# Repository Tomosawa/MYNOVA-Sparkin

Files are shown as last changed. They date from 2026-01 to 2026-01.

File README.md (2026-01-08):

# MYNOVA-Sparkin

[中文文档](README_CHS.md) | [English](README.md)

## Overview

MYNOVA-Sparkin is a wireless Bluetooth fingerprint recognition device for Windows computers. It provides fast fingerprint identification (0.5 seconds), local fingerprint management, and system login integration. The project includes complete hardware design, firmware, and Windows supporting software.

Sparkin Overview
Sparkin Overview
Sparkin Overview
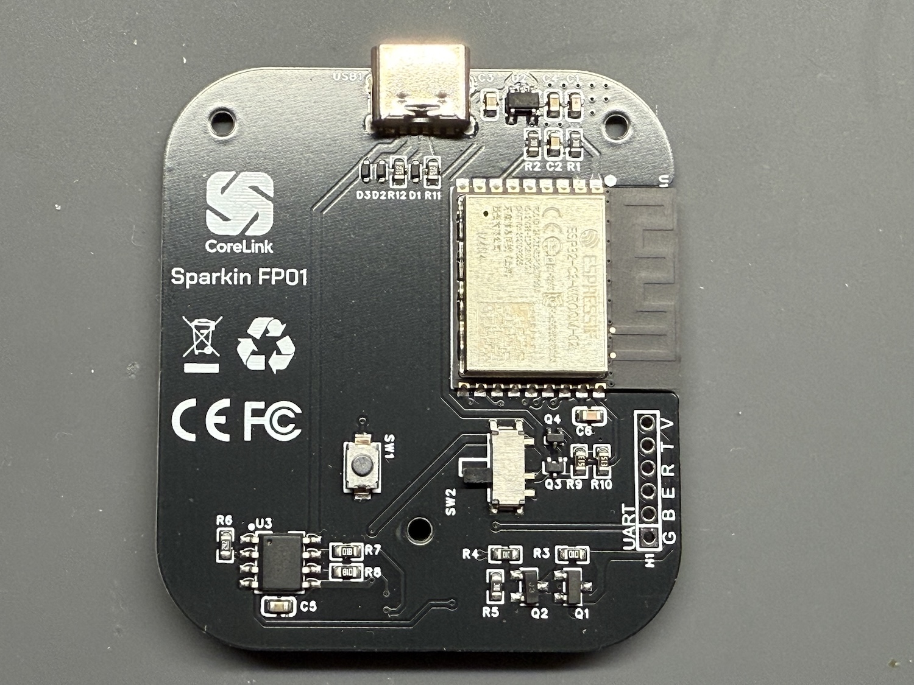
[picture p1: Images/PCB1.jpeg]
Sparkin PCB1

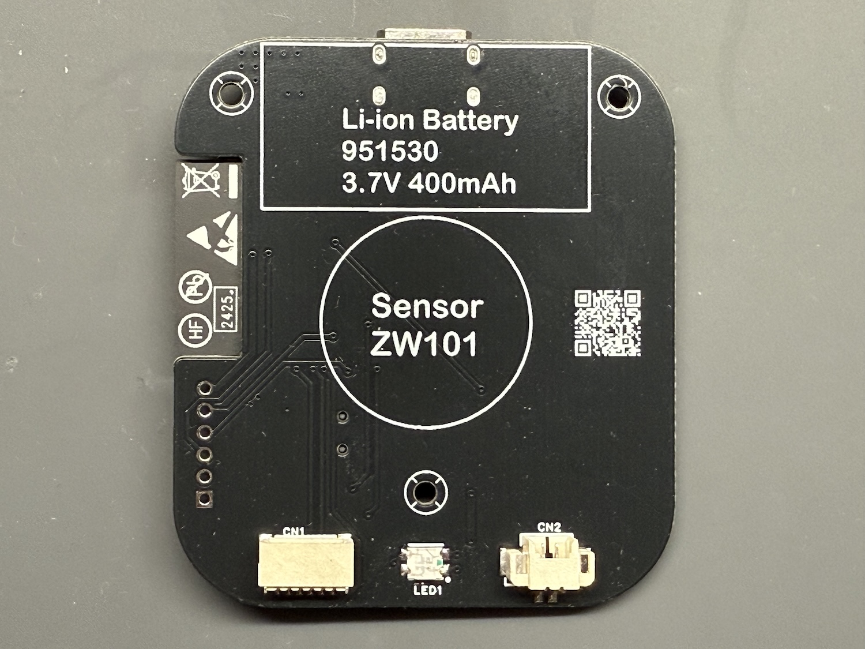
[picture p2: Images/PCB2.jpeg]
Sparkin PCB2

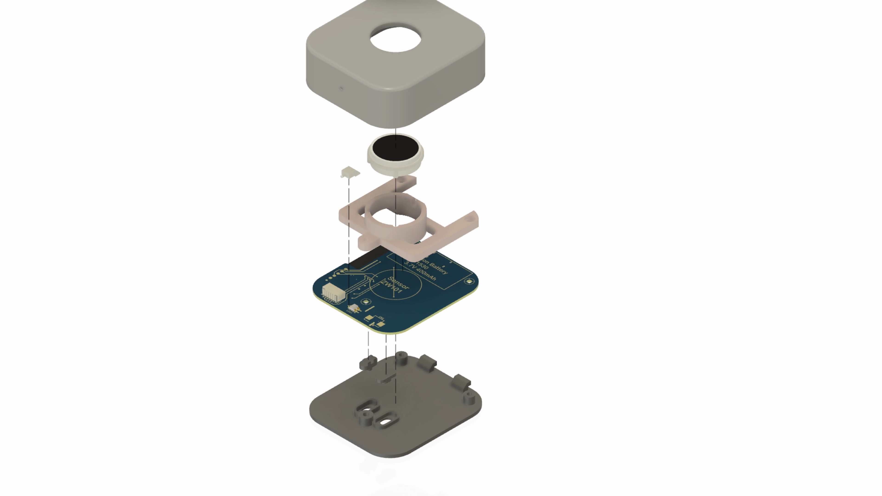
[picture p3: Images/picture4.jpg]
Sparkin Overview


## Key Features

- **Fast Recognition**: 0.5-second fingerprint identification
- **Wireless Connectivity**: Bluetooth BLE 5.0 for stable connections
- **System Integration**: Automatic Windows login when fingerprint is verified
- **Local Storage**: Fingerprints stored securely on the device
- **Portable Design**: Built-in battery with Type-C charging
- **Power Efficient**: Automatic sleep mode to conserve battery
- **OTA Updates**: Over-the-air firmware update support

## Getting Started

### Prerequisites

- Windows 10/11 computer with Bluetooth support
- Type-C charging cable (for initial device charging)

### Installation

1. Download the latest Windows installer from the [Releases](https://github.com/tomosawa/MYNOVA-Sparkin/releases) page
2. Run the installer and follow the on-screen instructions
3. After installation, the Sparkin service will start automatically
4. Launch the Sparkin configuration client from the Start menu

### Device Pairing

1. Press and hold the pairing button for 3 seconds until the LED blinks
2. Open the Sparkin configuration client
3. Click "Add Device" and select "Sparkin FP01"
4. Follow the instructions to complete pairing

### Fingerprint Enrollment

1. Ensure the device is connected
2. Go to "Fingerprint Management" in the client
3. Click "Enroll New Fingerprint"
4. Scan your fingerprint multiple times as instructed
5. Assign a name to the fingerprint

### System Login Setup

1. Go to "Login Settings" in the client
2. Enable "Automatic Login with Fingerprint"
3. Enter your Windows login password
4. Click "Save" to complete setup

## Project Structure

```
MYNOVA-Sparkin/
├── SparkinFW/          # Device firmware (Arduino/ESP32-C3)
├── SparkinWin/         # Windows application and setup
├── 3DModels/           # Enclosure 3D models
├── Labels/             # Label design files
└── PCB/                # PCB design files
```

### SparkinFW
Device firmware built on Arduino framework for ESP32-C3, featuring:
- Fingerprint sensor management
- Bluetooth BLE communication
- Power and battery management
- Sleep mode control
- OTA update support

### SparkinWin
Windows supporting applications:
- Background service for Bluetooth communication
- Configuration client for device management
- Fingerprint enrollment interface
- System login integration

## Development

### Firmware Development

- **IDE**: Arduino IDE 2.3.6+
- **ESP32 Core**: 3.1.1+
- **Language**: C++

### Windows Application Development

- **IDE**: Visual Studio 2022
- **Framework**: Windows SDK for Windows 10/11
- **Language**: C#/C++

## Documentation

For detailed technical documentation:
- [Firmware Architecture](docs/firmware-architecture.md)
- [Windows Application Guide](docs/windows-application.md)

## Contributing

Contributions are welcome! Please follow these steps:

1. Fork the repository
2. Create a feature branch
3. Make your changes
4. Submit a pull request

## Copyright Statement

This project is prohibited for any commercial use and is intended for learning and DIY purposes only.

## License [LICENSE](LICENSE)

This project is licensed under the [GPLv3](LICENSE). [GPLv3 (GNU General Public License version 3)](LICENSE) is a free, open-source software license that guarantees users the freedoms to run, study, share, and modify the software.
The complete text of the [GPLv3](LICENSE) license is included in the [LICENSE](LICENSE) file of this project. Before using, modifying, or distributing the code of this project, make sure you have read and understood the entire [GPLv3](LICENSE) license.

## Acknowledgments

- [Espressif Systems](https://www.espressif.com/) for ESP32-C3
- [Arduino Framework](https://www.arduino.cc/) community
- [Bluetooth SIG](https://www.bluetooth.com/) for BLE standards
- [Microsoft Learn](https://learn.microsoft.com/en-us/windows/win32/secauthn/credential-providers-in-windows) for Windows credential provider documentation
---

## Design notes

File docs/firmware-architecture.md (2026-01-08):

# SparkinFW Firmware Architecture

## Overview

SparkinFW is the firmware for the MYNOVA-Sparkin wireless Bluetooth fingerprint recognition device. It's built on the Arduino framework for the ESP32-C3 microcontroller and implements a modular architecture to manage all device functionalities.

## System Architecture

The firmware follows a modular design pattern with clear separation of concerns:

```
┌─────────────────────────────────────────────────────────────────┐
│                         Main Program                            │
│                        (SparkinFW.ino)                          │
└─────────────┬───────────────────┬───────────────────┬───────────┘
              │                   │                   │
┌─────────────▼─────────┐ ┌───────▼─────────────┐ ┌───▼───────────────┐
│  Fingerprint Module   │ │  Bluetooth Module   │ │ Power Management  │
│  (Fingerprint.cpp/h)  │ │  (BleKeyboard.cpp/h,│ │ (BatteryManager.  │
│                       │ │  BluetoothManager.  │ │  cpp/h, Sleep.cpp │
│                       │ │  cpp/h, BluetoothHa │ │  /h)              │
│                       │ │  ndle.cpp/h)        │ │                   │
└─────────────┬─────────┘ └───────┬─────────────┘ └─┬─────────────────┘
              │                   │                 │
┌─────────────▼─────────┐ ┌───────▼─────────────┐ ┌─▼─────────────────┐
│ Button Management     │ │ OTA Update          │ │ Config Management │
│ (ButtonHandle.cpp/h,  │ │ (BluetoothOTA.cpp/h)│ │ (ConfigManager.   │
│ ButtonTimer.cpp/h)    │ │                     │ │  cpp/h)           │
└─────────────┬─────────┘ └─────────────────────┘ └───────────────────┘
              │
┌─────────────▼─────────┐
│ Common Utilities      │
│ (Common.cpp/h, IOPin. │
│  h, Version.h)        │
└───────────────────────┘
```

## Core Modules

### 1. Main Program (SparkinFW.ino)

The main entry point that coordinates all modules:

- **setup()**: Initializes all hardware and software modules
- **loop()**: Main program loop handling continuous operations
- **Event handling**: Processes events from different modules
- **State management**: Maintains the overall device state

### 2. Fingerprint Module

**File**: `Fingerprint.cpp/h`

Responsible for all fingerprint-related operations:

- Initialization and configuration of the optical fingerprint sensor
- Fingerprint enrollment (storing new fingerprints)
- Fingerprint identification (matching against stored fingerprints)
- Fingerprint database management
- Fingerprint template encryption

### 3. Bluetooth Module

**Files**: `BluetoothManager.cpp/h`, `BleKeyboard.cpp/h`, `BluetoothHandle.cpp/h`

Handles all wireless communication:

- **BLE Server**: Manages Bluetooth connections and services
- **Characteristic Management**: Handles data exchange between device and Windows
- **Message Protocol**: Implements custom message format for communication
- **BleKeyboard**: Emulates keyboard input for Windows login
- **Advertising**: Manages device discovery and pairing
- **Connection Handling**: Manages Bluetooth connection states and events

Key Bluetooth UUIDs:
- Service UUID: `0000180f-0000-1000-8000-00805f9b34fb`
- Characteristic UUIDs: Custom for fingerprint data and commands

### 4. Power Management

**Files**: `BatteryManager.cpp/h`, `Sleep.cpp/h`

Manages device power consumption:

- **Battery Monitoring**: Measures battery voltage and level
- **Charging Management**: Handles Type-C charging state
- **Sleep Mode**: Automatic sleep after period of inactivity
- **Wake-up**: Fingerprint sensor or button wake-up triggers
- **Power Optimization**: Controls peripheral power states

### 5. Button Management

**Files**: `ButtonHandle.cpp/h`, `ButtonTimer.cpp/h`

Handles physical button operations:

- **Button Press Detection**: Monitors pairing button state
- **Long Press Handling**: 3-second press for pairing mode
- **Button Debouncing**: Eliminates false triggers
- **Timer Functions**: Implements timed button operations

### 6. OTA Update

**File**: `BluetoothOTA.cpp/h`

Enables over-the-air firmware updates:

- **Secure Updates**: Validates firmware signatures
- **Update Process**: Manages firmware download and installation
- **Rollback**: Automatic recovery if update fails
- **Version Check**: Ensures compatible firmware versions

### 7. Configuration Management

**File**: `ConfigManager.cpp/h`

Stores and retrieves device configuration:

- **Persistent Storage**: Uses ESP32 non-volatile storage
- **Configuration Parameters**:
  - Bluetooth name and settings
  - Sleep timeout
  - Fingerprint matching threshold
  - Device ID and settings
- **Factory Reset**: Restores default configuration

### 8. Common Utilities

**Files**: `Common.cpp/h`, `IOPin.h`, `Version.h`

Shared functionality across modules:

- **Pin Definitions**: Centralized IO pin mapping
- **Debug Functions**: Logging and debugging utilities
- **Version Information**: Firmware version tracking
- **Data Structures**: Common data types and structures
- **Helper Functions**: String manipulation, data conversion, etc.

## Main Program Flow

### Initialization Flow

```
1. System boot
2. Initialize common utilities and pin mappings
3. Initialize configuration manager
4. Initialize battery management
5. Initialize fingerprint module
6. Initialize Bluetooth services
7. Initialize button handling
8. Initialize sleep management
9. Start main loop
```

### Fingerprint Recognition Flow

```
1. Fingerprint sensor detects touch
2. Capture fingerprint image
3. Extract fingerprint features
4. Match against stored templates
5. If match found:
   a. Send success message via Bluetooth
   b. Trigger Windows login if configured
6. If no match:
   a. Send failure message via Bluetooth
   b. Optionally alert user (LED feedback)
```

## Communication Protocol

The device uses a custom binary protocol over Bluetooth BLE for communication with the Windows application:

### Message Format

```
┌────────────┬────────────┬───────────┐
│ Message ID │ Data Length│   Data    │
└────────────┴────────────┴───────────┘
  (1 byte)    (1 byte)    (N bytes)
```

### Key Message Types

| Message ID | Description | Direction |
|---|---|---|
| 0x01 | Fingerprint Search Result | Device → PC |
| 0x02 | Enroll Fingerprint Request | PC → Device |
| 0x03 | Enroll Fingerprint Result | Device → PC |
| 0x04 | Delete Fingerprint Request | PC → Device |
| 0x05 | Device Status Request | PC → Device |
| 0x06 | Device Status Response | Device → PC |
| 0x07 | Configuration Update | PC → Device |
| 0x08 | Sleep Mode Request | PC → Device |
| 0x09 | Wake-up Request | PC → Device |

## Power States

| State | Description | Power Consumption |
|---|---|---|
| Active | Full functionality | High |
| Standby | Bluetooth active, fingerprint sensor ready | Medium |
| Sleep | Bluetooth off, fingerprint sensor on standby | Low |
| Deep Sleep | Minimal functionality, wake-up on touch | Very Low |

## Development Guide

### Prerequisites

- Arduino IDE 2.3.6+
- ESP32 Core 3.1.1+
- ESP32-C3 development board
- Required libraries:
  - ESP32 BLE Arduino
  - ArduinoJson
  - Adafruit Fingerprint Sensor Library

### Building and Flashing

1. Open `SparkinFW.ino` in Arduino IDE
2. Select "ESP32C3 Dev Module" as the board
3. Select the appropriate port
4. Click "Upload" to flash the firmware

### Debugging

- Use Serial Monitor at 115200 baud for debug messages
- Check Bluetooth logs in Windows application
- Use LED indicators for device state (pairing, charging, etc.)

## Version History

| Version | Date | Changes |
|---|---|---|
| 1.0.0 | 2023-12-15 | Initial release |
| 1.0.1 | 2023-12-20 | Fixed battery reporting |
| 1.1 | 2024-01-05 | Added OTA update support |

---

[Back to README](../README.md)

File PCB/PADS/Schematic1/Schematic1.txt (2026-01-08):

*PADS-LOGIC-V9.0-CP936* from EasyEDA Pro
*SCH*
BORDER NAME Sheet_WMY_A4
*SHT* 2 P1 -1 $$$NONE
*TEXT*
2415 6165 0 0 348 10 0 "Regular Arial"
单片机
1965 4265 0 0 348 10 0 "Regular Arial"
3.3V供电电路
865 115 0 0 348 10 0 "Regular Arial"
Type-C插口（ESD）
2415 2075 0 0 348 10 0 "Regular Arial"
充电电路
3715 165 0 0 348 10 0 "Regular Arial"
电池插口
9765 865 0 0 348 10 0 "Regular Arial"
电量检测
6365 4265 0 0 348 10 0 "Regular Arial"
指纹模块低功耗控制
9615 4215 0 0 348 10 0 "Regular Arial"
指纹模块连接器
7065 815 0 0 348 10 0 "Regular Arial"
按钮/开关
5265 165 0 0 348 10 0 "Regular Arial"
螺丝孔
*LINES*
Sheet_WMY_A4 LINES 0 0 24 31
OPEN 2 10 255
7995 115
7995 715
OPEN 2 10 255
6815 715
6815 115
OPEN 2 10 255
11615 515
6215 515
OPEN 2 10 255
11615 715
6215 715
OPEN 2 10 255
9195 715
9195 115
OPEN 2 10 255
6215 715
6215 115
CLOSED 5 10 255
15 8265
11715 8265
11715 15
15 15
15 8265
CLOSED 5 10 255
115 8165
11615 8165
11615 115
115 115
115 8165
OPEN 2 10 255
1965 15
1965 115
OPEN 2 10 255
1965 8265
1965 8165
OPEN 2 10 255
3915 15
3915 115
OPEN 2 10 255
3915 8265
3915 8165
OPEN 2 10 255
5865 15
5865 115
OPEN 2 10 255
5865 8265
5865 8165
OPEN 2 10 255
7815 15
7815 115
OPEN 2 10 255
7815 8265
7815 8165
OPEN 2 10 255
9765 15
9765 115
OPEN 2 10 255
9765 8265
9765 8165
OPEN 2 10 255
15 6202
115 6202
OPEN 2 10 255
11715 6202
11615 6202
OPEN 2 10 255
15 4140
115 4140
OPEN 2 10 255
11715 4140
11615 4140
OPEN 2 10 255
15 2077
115 2077
OPEN 2 10 255
11715 2077
11615 2077
7415 615 0 12 208 10 0 "Regular 宋体"
创建日期
9265 625 0 8 208 10 0 "Regular 宋体"
页
10335 625 0 8 208 10 0 "Regular 宋体"
共
8615 615 0 12 208 10 0 "Regular 宋体"
更新日期
6515 615 0 12 208 10 0 "Regular 宋体"
作者
990 65 0 12 139 10 0 "Regular 宋体"
1
990 8215 0 12 139 10 0 "Regular 宋体"
1
2940 65 0 12 139 10 0 "Regular 宋体"
2
2940 8215 0 12 139 10 0 "Regular 宋体"
2
4890 65 0 12 139 10 0 "Regular 宋体"
3
4890 8215 0 12 139 10 0 "Regular 宋体"
3
6840 65 0 12 139 10 0 "Regular 宋体"
4
6840 8215 0 12 139 10 0 "Regular 宋体"
4
8790 65 0 12 139 10 0 "Regular 宋体"
5
8790 8215 0 12 139 10 0 "Regular 宋体"
5
10740 65 0 12 139 10 0 "Regular 宋体"
6
10740 8215 0 12 139 10 0 "Regular 宋体"
6
65 7233 0 12 139 10 0 "Regular 宋体"
A
11665 7233 0 12 139 10 0 "Regular 宋体"
A
65 5171 0 12 139 10 0 "Regular 宋体"
B
11665 5171 0 12 139 10 0 "Regular 宋体"
B
65 3108 0 12 139 10 0 "Regular 宋体"
C
11665 3108 0 12 139 10 0 "Regular 宋体"
C
65 1046 0 12 139 10 0 "Regular 宋体"
D
11665 1046 0 12 139 10 0 "Regular 宋体"
D
10415 315 0 12 278 10 0 "Regular Arial"
SparkinFP01
11035 625 0 12 208 10 0 "Regular Arial"
1
8615 315 0 12 208 10 0 "Regular Arial"
2025-07-31
7415 315 0 12 208 10 0 "Regular Arial"
2025-07-05
9865 625 0 12 208 10 0 "Regular Arial"
1
6315 315 0 8 208 10 0 "Regular Arial"
Tomosawa
$$Line1 LINES 0 0 1 0
OPEN 2 10 255
6215 715
6215 4115
$$Line2 LINES 0 0 1 0
OPEN 2 10 255
5615 6065
115 6065
$$Line3 LINES 0 0 1 0
OPEN 2 10 255
11615 4115
115 4115
$$Line4 LINES 0 0 1 0
OPEN 2 10 255
8815 4115
8815 715
$$Line5 LINES 0 0 1 0
OPEN 2 10 255
6215 1965
115 1965
$$Line6 LINES 0 0 1 0
OPEN 2 10 255
3365 1965
3365 115
$$Line7 LINES 0 0 1 0
OPEN 2 10 255
9015 8165
9015 4115
$$Line8 LINES 0 0 1 0
OPEN 2 10 255
4865 1965
4865 115
$$Line9 LINES 0 0 1 0
OPEN 2 10 255
5615 8165
5615 4115
*CAEDECAL*
PIN 0 0 100 10 100 10 2 1 0 0 0 1
TIMESTAMP 2026.01.08.09.08.44
"Default Font"
"Default Font"
0 0 0 0 94 6 0 "Regular default"
PART-TYPE
0 0 0 0 94 6 0 "Regular default"
REF-DES
OPEN 2 10 255
0 0
100 0
PIN_1 0 0 100 10 100 10 2 1 0 0 0 1
TIMESTAMP 2026.01.08.09.08.44
"Default Font"
"Default Font"
0 0 0 0 94 6 0 "Regular default"
PART-TYPE
0 0 0 0 94 6 0 "Regular default"
REF-DES
OPEN 2 10 255
0 0
150 0
PIN_2 0 0 100 10 100 10 2 1 0 0 0 1
TIMESTAMP 2026.01.08.09.08.44
"Default Font"
"Default Font"
0 0 0 0 94 6 0 "Regular default"
PART-TYPE
0 0 0 0 94 6 0 "Regular default"
REF-DES
OPEN 2 10 255
0 0
200 0
PIN_3 0 0 100 10 100 10 2 1 0 0 0 1
TIMESTAMP 2026.01.08.09.08.44
"Default Font"
"Default Font"
0 0 0 0 94 6 0 "Regular default"
PART-TYPE
0 0 0 0 94 6 0 "Regular default"
REF-DES
OPEN 2 10 255
0 0
20 0
PIN_4 0 0 100 10 100 10 2 1 0 0 0 1
TIMESTAMP 2026.01.08.09.08.44
"Default Font"
"Default Font"
0 0 0 0 94 6 0 "Regular default"
PART-TYPE
0 0 0 0 94 6 0 "Regular default"
REF-DES
OPEN 2 10 255
0 0
50 0
PZ200V-11-06P 0 0 100 10 100 10 2 2 0 6 0 0
TIMESTAMP 2026.01.08.09.08.44
"Default Font"
"Default Font"
0 0 0 0 94 6 0 "Regular default"
PART-TYPE
0 0 0 0 94 6 0 "Regular default"
REF-DES
CLOSED 5 10 255
-100 350
100 350
100 -350
-100 -350
-100 350
CIRCLE 2 10 255
-35 300
-65 300
T-200 250 0 0 50 10 0 4 110 -30 0 0 PIN
P-100 0 0 1 0 0 0 0 128
T-200 150 0 0 50 10 0 4 110 -30 0 0 PIN
P-100 0 0 1 0 0 0 0 128
T-200 50 0 0 50 10 0 4 110 -30 0 0 PIN
P-100 0 0 1 0 0 0 0 128
T-200 -50 0 0 50 10 0 4 110 -30 0 0 PIN
P-100 0 0 1 0 0 0 0 128
T-200 -150 0 0 50 10 0 4 110 -30 0 0 PIN
P-100 0 0 1 0 0 0 0 128
T-200 -250 0 0 50 10 0 4 110 -30 0 0 PIN
P-100 0 0 1 0 0 0 0 128
ESP32-C3-WROOM-02-N4(4MB) 0 0 100 10 100 10 2 2 0 19 0 0
TIMESTAMP 2026.01.08.09.08.44
"Default Font"
"Default Font"
0 0 0 0 94 6 0 "Regular default"
PART-TYPE
0 0 0 0 11 10 0 "Regular Arial"
REF-DES
CIRCLE 2 10 255
-235 500
-265 500
CLOSED 5 10 255
-300 550
300 550
300 -550
-300 -550
-300 550
T400 450 0 1 50 10 0 4 110 -30 0 0 PIN
P-100 0 0 1 0 0 0 0 128
T400 350 0 1 50 10 0 4 110 -30 0 0 PIN
P-100 0 0 1 0 0 0 0 128
T400 250 0 1 50 10 0 4 110 -30 0 0 PIN
P-100 0 0 1 0 0 0 0 128
T400 150 0 1 50 10 0 4 110 -30 0 0 PIN
P-100 0 0 1 0 0 0 0 128
T400 50 0 1 50 10 0 4 110 -30 0 0 PIN
P-100 0 0 1 0 0 0 0 128
T400 -50 0 1 50 10 0 4 110 -30 0 0 PIN
P-100 0 0 1 0 0 0 0 128
T400 -150 0 1 50 10 0 4 110 -30 0 0 PIN
P-100 0 0 1 0 0 0 0 128
T400 -250 0 1 50 10 0 4 110 -30 0 0 PIN
P-100 0 0 1 0 0 0 0 128
T400 -350 0 1 50 10 0 4 110 -30 0 0 PIN
P-100 0 0 1 0 0 0 0 128
T400 -450 0 1 50 10 0 4 110 -30 0 0 PIN
P-100 0 0 1 0 0 0 0 128
T-400 -450 0 0 50 10 0 4 110 -30 0 0 PIN
P-100 0 0 1 0 0 0 0 128
T-400 -350 0 0 50 10 0 4 110 -30 0 0 PIN
P-100 0 0 1 0 0 0 0 128
T-400 -250 0 0 50 10 0 4 110 -30 0 0 PIN
P-100 0 0 1 0 0 0 0 128
T-400 -150 0 0 50 10 0 4 110 -30 0 0 PIN
P-100 0 0 1 0 0 0 0 128
T-400 -50 0 0 50 10 0 4 110 -30 0 0 PIN
P-100 0 0 1 0 0 0 0 128
T-400 50 0 0 50 10 0 4 110 -30 0 0 PIN
P-100 0 0 1 0 0 0 0 128
T-400 150 0 0 50 10 0 4 110 -30 0 0 PIN
P-100 0 0 1 0 0 0 0 128
T-400 250 0 0 50 10 0 4 110 -30 0 0 PIN
P-100 0 0 1 0 0 0 0 128
T-400 350 0 0 50 10 0 4 110 -30 0 0 PIN
P-100 0 0 1 0 0 0 0 128
5-Voltage 0 0 100 10 100 10 2 3 0 1 26 0
TIMESTAMP 2026.01.08.09.08.44
"Default Font"
"Default Font"
0 0 0 0 94 6 0 "Regular default"
PART-TYPE
0 0 0 0 94 6 0 "Regular default"
REF-DES
OPEN 2 10 255
-50 100
50 100
OPEN 2 10 255
0 100
0 50
OPEN 2 10 255
0 0
0 50
T0 0 90 0 0 10 0 4 10 -30 0 0 
P-100 0 0 1 0 0 0 0 128
Ground-GND 0 0 100 10 100 10 2 5 0 1 26 0
TIMESTAMP 2026.01.08.09.08.44
"Default Font"
"Default Font"
11 -10 0 0 11 10 0 "Regular Arial"
PART-TYPE
0 0 0 0 11 10 0 "Regular Arial"
REF-DES
OPEN 2 10 255
-100 -100
100 -100
OPEN 2 10 255
-10 -190
10 -190
OPEN 2 10 255
-40 -160
40 -160
OPEN 2 10 255
-70 -130
70 -130
OPEN 2 10 255
0 0
-0 -100
T0 0 90 2 0 10 0 4 10 -30 0 0 
P-100 0 0 1 0 0 0 0 128
电阻 0 0 100 10 100 10 2 1 0 2 0 0
TIMESTAMP 2026.01.08.09.08.44
"Default Font"
"Default Font"
0 0 0 0 94 6 0 "Regular default"
PART-TYPE
0 0 0 0 94 6 0 "Regular default"
REF-DES
CLOSED 5 10 255
-100 40
100 40
100 -40
-100 -40
-100 40
T200 0 0 1 50 10 0 4 110 -30 0 0 PIN
P-100 0 0 1 0 0 0 0 128
T-200 0 0 0 50 10 0 4 110 -30 0 0 PIN
P-100 0 0 1 0 0 0 0 128
CL10A105KO8NNNC 0 0 100 10 100 10 2 4 0 2 0 0
TIMESTAMP 2026.01.08.09.08.44
"Default Font"
"Default Font"
0 0 0 0 94 6 0 "Regular default"
PART-TYPE
0 0 0 0 11 10 0 "Regular Arial"
REF-DES
OPEN 2 10 255
-20 80
-20 -80
OPEN 2 10 255
20 80
20 -80
OPEN 2 10 255
-50 0
-20 0
OPEN 2 10 255
20 0
50 0
T-150 0 0 0 50 10 0 4 110 -30 0 0 PIN
P-100 0 0 1 0 0 0 0 128
T150 0 0 1 50 10 0 4 110 -30 0 0 PIN
P-100 0 0 1 0 0 0 0 128
CapAcitance 0 0 100 10 100 10 2 4 0 2 0 0
TIMESTAMP 2026.01.08.09.08.44
"Default Font"
"Default Font"
0 0 0 0 94 6 0 "Regular default"
PART-TYPE
0 0 0 0 94 6 0 "Regular default"
REF-DES
OPEN 2 10 255
-20 -80
-20 80
OPEN 2 10 255
100 0
20 0
OPEN 2 10 255
20 80
20 -80
OPEN 2 10 255
-20 0
-100 0
T-200 0 0 0 50 10 0 4 110 -30 0 0 PIN
P-100 0 0 1 0 0 0 0 128
T200 0 0 1 50 10 0 4 110 -30 0 0 PIN
P-100 0 0 1 0 0 0 0 128
Netport-OUT 0 0 100 10 100 10 2 2 0 1 0 0
TIMESTAMP 2026.01.08.09.08.44
"Default Font"
"Default Font"
45 0 0 8 14 10 0 "Regular Arial"
PART-TYPE
0 0 0 0 14 10 0 "Regular Arial"
REF-DES
CLOSED 6 10 255
100 50
300 50
400 0
300 -50
100 -50
100 50
OPEN 2 10 255
0 0
100 0
T0 0 0 0 0 10 0 4 10 -30 0 0 
P-100 0 0 1 0 0 0 0 128
ME6211C33M5G-N 0 0 100 10 100 10 2 3 0 5 0 0
TIMESTAMP 2026.01.08.09.08.44
"Default Font"
"Default Font"
0 0 0 0 94 6 0 "Regular default"
PART-TYPE
0 0 0 0 11 10 0 "Regular Arial"
REF-DES
CIRCLE 2 10 255
-335 170
-365 170
CIRCLE 2 10 255
-335 170
-365 170
CLOSED 5 10 255
-400 220
400 220
400 -220
-400 -220
-400 220
T-500 100 0 0 50 10 0 4 110 -30 0 0 PIN
P-100 0 0 1 0 0 0 0 128
T-500 0 0 0 50 10 0 4 110 -30 0 0 PIN
P-100 0 0 1 0 0 0 0 128
T-500 -100 0 0 50 10 0 4 110 -30 0 0 PIN
P-100 0 0 1 0 0 0 0 128
T500 -100 0 1 50 10 0 4 110 -30 0 0 PIN
P-100 0 0 1 0 0 0 0 128
T500 100 0 1 50 10 0 4 110 -30 0 0 PIN
P-100 0 0 1 0 0 0 0 128
Netport-IN 0 0 100 10 100 10 2 2 0 1 0 0
TIMESTAMP 2026.01.08.09.08.44
"Default Font"
"Default Font"
-45 0 0 9 14 10 0 "Regular Arial"
PART-TYPE
0 0 0 0 14 10 0 "Regular Arial"
REF-DES
CLOSED 6 10 255
-100 0
-200 50
-400 50
-400 -50
-200 -50
-100 0
OPEN 2 10 255
0 0
-100 0
T0 0 0 1 0 10 0 4 10 -30 0 0 
P-100 0 0 1 0 0 0 0 128
CL21A106KAYNNNE 0 0 100 10 100 10 2 4 0 2 0 0
TIMESTAMP 2026.01.08.09.08.44
"Default Font"
"Default Font"
0 0 0 0 94 6 0 "Regular default"
PART-TYPE
0 0 0 0 11 10 0 "Regular Arial"
REF-DES
OPEN 2 10 255
-20 0
-100 0
OPEN 2 10 255
20 80
20 -80
OPEN 2 10 255
100 0
20 0
OPEN 2 10 255
-20 -80
-20 80
T200 0 0 1 50 10 0 4 110 -30 0 0 PIN
P-100 0 0 1 0 0 0 0 128
T-200 0 0 0 50 10 0 4 110 -30 0 0 PIN
P-100 0 0 1 0 0 0 0 128
TS-1088-AR02016 0 0 100 10 100 10 2 3 0 2 0 0
TIMESTAMP 2026.01.08.09.08.44
"Default Font"
"Default Font"
0 0 0 0 94 6 0 "Regular default"
PART-TYPE
0 0 0 0 11 10 0 "Regular Arial"
REF-DES
OPEN 2 10 255
-90 20
80 70
OPEN 2 10 255
200 0
100 0
OPEN 2 10 255
-200 0
-100 0
T300 0 0 1 50 10 0 4 110 -30 0 0 PIN
P-100 0 0 1 0 0 0 0 128
T-300 0 0 0 50 10 0 4 110 -30 0 0 PIN
P-100 0 0 1 0 0 0 0 128
VBUS 0 0 100 10 100 10 2 2 0 1 0 0
TIMESTAMP 2026.01.08.09.08.44
"Default Font"
"Default Font"
0 0 0 0 94 6 0 "Regular default"
PART-TYPE
0 0 0 0 94 6 0 "Regular default"
REF-DES
CLOSED 10 10 255
0 0
-50 -50
-50 -50
-200 -50
-200 -50
-200 50
-200 50
-50 50
-50 50
0 0
OPEN 2 10 255
0 0
0 0
T0 0 0 0 0 10 0 4 10 -30 0 0 
P-100 0 0 1 0 0 0 0 128
GND 0 0 100 10 100 10 2 6 0 1 26 0
TIMESTAMP 2026.01.08.09.08.44
"Default Font"
"Default Font"
0 0 0 0 94 6 0 "Regular default"
PART-TYPE
0 0 0 0 94 6 0 "Regular default"
REF-DES
OPEN 2 10 255
0 -100
0 0
OPEN 2 10 255
-90 -100
90 -100
OPEN 2 10 255
-60 -120
60 -120
OPEN 2 10 255
-30 -140
30 -140
OPEN 2 10 255
-10 -160
10 -160
OPEN 2 10 255
0 0
0 0
T0 0 0 0 0 10 0 4 10 -30 0 0 
P-100 0 0 1 0 0 0 0 128
B+ 0 0 100 10 100 10 2 3 0 1 26 0
TIMESTAMP 2026.01.08.09.08.44
"Default Font"
"Default Font"
0 0 0 0 94 6 0 "Regular default"
PART-TYPE
0 0 0 0 94 6 0 "Regular default"
REF-DES
OPEN 2 10 255
0 100
0 0
OPEN 2 10 255
-50 100
50 100
OPEN 2 10 255
0 0
0 0
T0 0 0 0 0 10 0 4 10 -30 0 0 
P-100 0 0 1 0 0 0 0 128
TP4056 0 0 100 10 100 10 2 2 0 9 0 0
TIMESTAMP 2026.01.08.09.08.44
"Default Font"
"Default Font"
0 0 0 0 94 6 0 "Regular default"
PART-TYPE
0 0 0 0 11 10 0 "Regular Arial"
REF-DES
CLOSED 5 10 255
-400 300
400 300
400 -300
-400 -300
-400 300
CIRCLE 2 10 255
-335 250
-365 250
T-500 100 0 0 50 10 0 4 110 -30 0 0 PIN
P-100 0 0 1 0 0 0 0 128
T-500 0 0 0 50 10 0 4 110 -30 0 0 PIN
P-100 0 0 1 0 0 0 0 128
T-500 -100 0 0 50 10 0 4 110 -30 0 0 PIN
P-100 0 0 1 0 0 0 0 128
T-500 -200 0 0 50 10 0 4 110 -30 0 0 PIN
P-100 0 0 1 0 0 0 0 128
T500 -200 0 1 50 10 0 4 110 -30 0 0 PIN
P-100 0 0 1 0 0 0 0 128
T500 -100 0 1 50 10 0 4 110 -30 0 0 PIN
P-100 0 0 1 0 0 0 0 128
T500 0 0 1 50 10 0 4 110 -30 0 0 PIN
P-100 0 0 1 0 0 0 0 128
T500 100 0 1 50 10 0 4 110 -30 0 0 PIN
P-100 0 0 1 0 0 0 0 128
T500 200 0 1 50 10 0 4 110 -30 0 0 PIN
P-100 0 0 1 0 0 0 0 128
0603WAF1201T5E 0 0 100 10 100 10 2 1 0 2 0 0
TIMESTAMP 2026.01.08.09.08.44
"Default Font"
"Default Font"
0 0 0 0 94 6 0 "Regular default"
PART-TYPE
0 0 0 0 11 10 0 "Regular Arial"
REF-DES
CLOSED 5 10 255
-100 40
100 40
100 -40
-100 -40
-100 40
T200 0 0 1 50 10 0 4 110 -30 0 0 PIN
P-100 0 0 1 0 0 0 0 128
T-200 0 0 0 50 10 0 4 110 -30 0 0 PIN
P-100 0 0 1 0 0 0 0 128
CL21A106KAYNNNE_1 0 0 100 10 100 10 2 4 0 2 0 0
TIMESTAMP 2026.01.08.09.08.44
"Default Font"
"Default Font"
0 0 0 0 94 6 0 "Regular default"
PART-TYPE
0 0 0 0 11 10 0 "Regular Arial"
REF-DES
OPEN 2 10 255
-20 0
-100 0
OPEN 2 10 255
20 80
20 -80
OPEN 2 10 255
100 0
20 0
OPEN 2 10 255
-20 -80
-20 80
T200 0 0 1 50 10 0 4 110 -30 0 0 PIN
P-100 0 0 1 0 0 0 0 128
T-200 0 0 0 50 10 0 4 110 -30 0 0 PIN
P-100 0 0 1 0 0 0 0 128
HC-1.25-2PWT 0 0 100 10 100 10 2 2 0 4 0 0
TIMESTAMP 2026.01.08.09.08.44
"Default Font"
"Default Font"
0 0 0 0 94 6 0 "Regular default"
PART-TYPE
0 0 0 0 11 10 0 "Regular Arial"
REF-DES
CLOSED 5 10 255
-100 250
200 250
200 -250
-100 -250
-100 250
CIRCLE 2 10 255
-35 -150
-65 -150
T-200 -50 0 0 50 10 0 4 110 -30 0 0 PIN
P-100 0 0 1 0 0 0 0 128
T-200 50 0 0 50 10 0 4 110 -30 0 0 PIN
P-100 0 0 1 0 0 0 0 128
T50 -350 90 0 50 10 0 4 110 -30 0 0 PIN
P-100 0 0 1 0 0 0 0 128
T50 350 90 2 50 10 0 4 110 -30 0 0 PIN
P-100 0 0 1 0 0 0 0 128
RC0603FR-071KL 0 0 100 10 100 10 2 1 0 2 0 0
TIMESTAMP 2026.01.08.09.08.44
"Default Font"
"Default Font"
0 0 0 0 94 6 0 "Regular default"
PART-TYPE
0 0 0 0 11 10 0 "Regular Arial"
REF-DES
CLOSED 5 10 255
-100 40
100 40
100 -40
-100 -40
-100 40
T200 0 0 1 50 10 0 4 110 -30 0 0 PIN
P-100 0 0 1 0 0 0 0 128
T-200 0 0 0 50 10 0 4 110 -30 0 0 PIN
P-100 0 0 1 0 0 0 0 128
XL-3227SURUGC 0 0 100 10 100 10 2 12 0 4 0 0
TIMESTAMP 2026.01.08.09.08.44
"Default Font"
"Default Font"
0 0 0 0 94 6 0 "Regular default"
PART-TYPE
0 0 0 0 11 10 0 "Regular Arial"
REF-DES
CLOSED 6 10 255
-155 15
-135 -25
-135 -25
-115 -5
-115 -5
-155 15
CLOSED 6 10 255
-115 55
-95 15
-95 15
-75 35
-75 35
-115 55
OPEN 2 10 255
-85 -55
-155 15
OPEN 2 10 255
-45 -15
-115 55
CLOSED 6 10 255
-115 255
-75 235
-75 235
-95 215
-95 215
-115 255
CLOSED 6 10 255
-155 215
-115 195
-115 195
-135 175
-135 175
-155 215
OPEN 2 10 255
-45 185
-115 255
OPEN 2 10 255
-85 145
-155 215
OPEN 2 10 255
-50 170
-50 30
CLOSED 6 10 255
50 160
-50 100
-50 100
50 30
50 30
50 160
OPEN 2 10 255
-50 -30
-50 -170
CLOSED 6 10 255
50 -40
-50 -100
-50 -100
50 -170
50 -170
50 -40
T-200 100 0 0 75 10 0 4 160 -30 0 0 PIN_1
P-100 0 0 1 0 0 0 0 128
T200 100 0 1 75 10 0 4 160 -30 0 0 PIN_1
P-100 0 0 1 0 0 0 0 128
T200 -100 0 1 75 10 0 4 160 -30 0 0 PIN_1
P-100 0 0 1 0 0 0 0 128
T-200 -100 0 0 75 10 0 4 160 -30 0 0 PIN_1
P-100 0 0 1 0 0 0 0 128
TYPE-C_6P(073) 0 0 100 10 100 10 2 2 0 7 0 0
TIMESTAMP 2026.01.08.09.08.44
"Default Font"
"Default Font"
0 0 0 0 94 6 0 "Regular default"
PART-TYPE
0 0 0 0 11 10 0 "Regular Arial"
REF-DES
CIRCLE 2 10 255
-235 250
-265 250
CLOSED 5 10 255
-300 300
300 300
300 -400
-300 -400
-300 300
T500 0 0 1 100 10 0 4 210 -30 0 0 PIN_2
P-100 0 0 1 0 0 0 0 128
T-500 -300 0 0 100 10 0 4 210 -30 0 0 PIN_2
P-100 0 0 1 0 0 0 0 128
T-500 -200 0 0 100 10 0 4 210 -30 0 0 PIN_2
P-100 0 0 1 0 0 0 0 128
T-500 0 0 0 100 10 0 4 210 -30 0 0 PIN_2
P-100 0 0 1 0 0 0 0 128
T-500 -100 0 0 100 10 0 4 210 -30 0 0 PIN_2
P-100 0 0 1 0 0 0 0 128
T-500 100 0 0 100 10 0 4 210 -30 0 0 PIN_2
P-100 0 0 1 0 0 0 0 128
T-500 200 0 0 100 10 0 4 210 -30 0 0 PIN_2
P-100 0 0 1 0 0 0 0 128
MSK12C02G25-B 0 0 100 10 100 10 2 15 0 5 0 0
TIMESTAMP 2026.01.08.09.08.44
"Default Font"
"Default Font"
0 0 0 0 94 6 0 "Regular default"
PART-TYPE
0 0 0 0 11 10 0 "Regular Arial"
REF-DES
OPEN 2 10 255
0 100
0 30
OPEN 2 10 255
0 30
0 0
OPEN 6 10 255
0 70
-150 70
-150 70
-150 0
-150 0
-140 30
OPEN 2 10 255
-150 0
-160 30
CLOSED 18 10 255
-170 0
-120 0
-120 0
-120 -50
-120 -50
70 -50
70 -50
70 0
70 0
130 0
130 0
130 -100
130 -100
-180 -100
-180 -100
-180 0
-180 0
-170 0
OPEN 4 10 255
100 100
100 0
100 0
110 30
OPEN 2 10 255
100 0
90 30
OPEN 2 10 255
0 0
10 30
OPEN 2 10 255
0 0
-10 30
OPEN 2 10 255
-200 0
-210 30
OPEN 2 10 255
-200 0
-190 30
OPEN 2 10 255
-200 30
-200 0
OPEN 2 10 255
-200 100
-200 30
CLOSED 5 10 255
-300 100
200 100
200 -200
-300 -200
-300 100
CLOSED 5 10 255
0 -200
100 -200
100 -300
0 -300
0 -200
T-200 300 90 2 100 10 0 4 210 -30 0 0 PIN_2
P-100 0 0 1 0 0 0 0 128
T0 300 90 2 100 10 0 4 210 -30 0 0 PIN_2
P-100 0 0 1 0 0 0 0 128
T100 300 90 2 100 10 0 4 210 -30 0 0 PIN_2
P-100 0 0 1 0 0 0 0 128
T400 -100 0 1 100 10 0 4 210 -30 0 0 PIN_2
P-100 0 0 1 0 0 0 0 128
T-500 -100 0 0 100 10 0 4 210 -30 0 0 PIN_2
P-100 0 0 1 0 0 0 0 128
DTA144EE_C2991974 0 0 100 10 100 10 2 7 0 3 0 0
TIMESTAMP 2026.01.08.09.08.44
"Default Font"
"Default Font"
0 0 0 0 94 6 0 "Regular default"
PART-TYPE
0 0 0 0 11 10 0 "Regular Arial"
REF-DES
OPEN 2 10 255
230 0
200 20
OPEN 18 10 255
100 -150
100 -110
100 -110
130 -100
130 -100
70 -80
70 -80
130 -60
130 -60
70 -40
70 -40
130 -20
130 -20
70 0
70 0
100 10
100 10
100 50
OPEN 20 10 255
-100 50
-60 50
-60 50
-50 20
-50 20
-30 80
-30 80
-10 20
-10 20
10 80
10 80
30 20
30 20
50 80
50 80
60 50
60 50
100 50
100 50
200 50
OPEN 6 10 255
230 0
300 -50
300 -50
300 -150
300 -150
100 -150
OPEN 2 10 255
200 -40
200 140
OPEN 2 10 255
200 80
300 150
CLOSED 6 10 255
200 20
260 10
260 10
230 -30
230 -30
200 20
T300 -350 90 0 100 10 0 4 210 -30 0 0 PIN_2
P-100 0 0 1 0 0 0 0 128
T-300 50 0 0 100 10 0 4 210 -30 0 0 PIN_2
P-100 0 0 1 0 0 0 0 128
T300 350 90 2 100 10 0 4 210 -30 0 0 PIN_2
P-100 0 0 1 0 0 0 0 128
2N7002T 0 0 100 10 100 10 2 11 0 3 0 0
TIMESTAMP 2026.01.08.09.08.44
"Default Font"
"Default Font"
0 0 0 0 94 6 0 "Regular default"
PART-TYPE
0 0 0 0 11 10 0 "Regular Arial"
REF-DES
CLOSED 6 10 255
0 0
60 -20
60 -20
60 20
60 20
0 0
CLOSED 6 10 255
200 20
170 -30
170 -30
230 -30
230 -30
200 20
OPEN 8 10 255
0 70
100 70
100 70
100 100
100 100
200 100
200 100
200 20
OPEN 8 10 255
0 0
100 0
100 0
100 -100
100 -100
200 -100
200 -100
200 -30
OPEN 2 10 255
100 -70
0 -70
OPEN 2 10 255
-20 90
-20 -90
OPEN 2 10 255
0 90
0 50
OPEN 2 10 255
0 -20
0 20
OPEN 2 10 255
0 -90
0 -50
OPEN 2 10 255
-100 0
-20 0
OPEN 6 10 255
240 20
220 20
220 20
180 20
180 20
160 20
T100 200 90 2 50 10 0 4 110 -30 0 0 PIN
P-100 0 0 1 0 0 0 0 128
T-200 0 0 0 50 10 0 4 110 -30 0 0 PIN
P-100 0 0 1 0 0 0 0 128
T100 -200 90 0 50 10 0 4 110 -30 0 0 PIN
P-100 0 0 1 0 0 0 0 128
RT0603BRD0720KL 0 0 100 10 100 10 2 1 0 2 0 0
TIMESTAMP 2026.01.08.09.08.44
"Default Font"
"Default Font"
0 0 0 0 94 6 0 "Regular default"
PART-TYPE
0 0 0 0 11 10 0 "Regular Arial"
REF-DES
CLOSED 5 10 255
-100 50
100 50
100 -50
-100 -50
-100 50
T200 0 0 1 50 10 0 4 110 -30 0 0 PIN
P-100 0 0 1 0 0 0 0 128
T-200 0 0 0 50 10 0 4 110 -30 0 0 PIN
P-100 0 0 1 0 0 0 0 128
RT0603BRD0750KL 0 0 100 10 100 10 2 1 0 2 0 0
TIMESTAMP 2026.01.08.09.08.44
"Default Font"
"Default Font"
0 0 0 0 94 6 0 "Regular default"
PART-TYPE
0 0 0 0 11 10 0 "Regular Arial"
REF-DES
CLOSED 5 10 255
-100 50
100 50
100 -50
-100 -50
-100 50
T200 0 0 1 50 10 0 4 110 -30 0 0 PIN
P-100 0 0 1 0 0 0 0 128
T-200 0 0 0 50 10 0 4 110 -30 0 0 PIN
P-100 0 0 1 0 0 0 0 128
WAFER-SH1.0-6PWB 0 0 100 10 100 10 2 2 0 8 0 0
TIMESTAMP 2026.01.08.09.08.44
"Default Font"
"Default Font"
0 0 0 0 94 6 0 "Regular default"
PART-TYPE
0 0 0 0 11 10 0 "Regular Arial"
REF-DES
CLOSED 5 10 255
-100 350
100 350
100 -350
-100 -350
-100 350
CIRCLE 2 10 255
-35 300
-65 300
T-200 250 0 0 50 10 0 4 110 -30 0 0 PIN
P-100 0 0 1 0 0 0 0 128
T-200 150 0 0 50 10 0 4 110 -30 0 0 PIN
P-100 0 0 1 0 0 0 0 128
T-200 50 0 0 50 10 0 4 110 -30 0 0 PIN
P-100 0 0 1 0 0 0 0 128
T-200 -50 0 0 50 10 0 4 110 -30 0 0 PIN
P-100 0 0 1 0 0 0 0 128
T-200 -150 0 0 50 10 0 4 110 -30 0 0 PIN
P-100 0 0 1 0 0 0 0 128
T-200 -250 0 0 50 10 0 4 110 -30 0 0 PIN
P-100 0 0 1 0 0 0 0 128
T50 -450 90 0 50 10 0 4 110 -30 0 0 PIN
P-100 0 0 1 0 0 0 0 128
T50 450 90 2 50 10 0 4 110 -30 0 0 PIN
P-100 0 0 1 0 0 0 0 128
0603WAF1003T5E 0 0 100 10 100 10 2 1 0 2 0 0
TIMESTAMP 2026.01.08.09.08.44
"Default Font"
"Default Font"
0 0 0 0 94 6 0 "Regular default"
PART-TYPE
0 0 0 0 11 10 0 "Regular Arial"
REF-DES
CLOSED 5 10 255
-100 40
100 40
100 -40
-100 -40
-100 40
T200 0 0 1 50 10 0 4 110 -30 0 0 PIN
P-100 0 0 1 0 0 0 0 128
T-200 0 0 0 50 10 0 4 110 -30 0 0 PIN
P-100 0 0 1 0 0 0 0 128
0603WAF5101T5E 0 0 100 10 100 10 2 1 0 2 0 0
TIMESTAMP 2026.01.08.09.08.44
"Default Font"
"Default Font"
0 0 0 0 94 6 0 "Regular default"
PART-TYPE
0 0 0 0 11 10 0 "Regular Arial"
REF-DES
CLOSED 5 10 255
-100 40
100 40
100 -40
-100 -40
-100 40
T200 0 0 1 50 10 0 4 110 -30 0 0 PIN
P-100 0 0 1 0 0 0 0 128
T-200 0 0 0 50 10 0 4 110 -30 0 0 PIN
P-100 0 0 1 0 0 0 0 128
SI2301_C2891731 0 0 100 10 100 10 2 11 0 3 0 0
TIMESTAMP 2026.01.08.09.08.44
"Default Font"
"Default Font"
0 0 0 0 94 6 0 "Regular default"
PART-TYPE
0 0 0 0 94 6 0 "Regular default"
REF-DES
OPEN 5 10 255
-100 70
0 70
0 100
100 100
100 20
OPEN 5 10 255
-100 0
0 0
0 -100
100 -100
100 -30
OPEN 2 10 255
0 -70
-100 -70
OPEN 2 10 255
-120 90
-120 -90
OPEN 2 10 255
-100 90
-100 50
OPEN 2 10 255
-100 -20
-100 20
OPEN 2 10 255
-100 -90
-100 -50
OPEN 2 10 255
-150 0
-120 0
CLOSED 4 10 255
-20 0
-80 20
-80 -20
-20 0
CLOSED 4 10 255
100 -25
130 25
70 25
100 -25
OPEN 4 10 255
60 -25
80 -25
120 -25
140 -25
T0 200 90 2 50 10 0 4 110 -30 0 0 PIN
P-100 0 0 1 0 0 0 0 128
T-250 0 0 0 50 10 0 4 110 -30 0 0 PIN
P-100 0 0 1 0 0 0 0 128
T0 -200 90 0 50 10 0 4 110 -30 0 0 PIN
P-100 0 0 1 0 0 0 0 128
S9013_C2891800 0 0 100 10 100 10 2 4 0 3 0 0
TIMESTAMP 2026.01.08.09.08.44
"Default Font"
"Default Font"
0 0 0 0 94 6 0 "Regular default"
PART-TYPE
0 0 0 0 11 10 0 "Regular Arial"
REF-DES
OPEN 2 10 255
100 100
0 30
OPEN 2 10 255
0 -30
100 -100
OPEN 2 10 255
0 90
0 -90
CLOSED 6 10 255
100 -100
70 -50
70 -50
40 -90
40 -90
100 -100
T100 200 90 2 50 10 0 4 110 -30 0 0 PIN
P-100 0 0 1 0 0 0 0 128
T-100 0 0 0 50 10 0 4 110 -30 0 0 PIN
P-100 0 0 1 0 0 0 0 128
T100 -200 90 0 50 10 0 4 110 -30 0 0 PIN
P-100 0 0 1 0 0 0 0 128
0603WAF1002T5E 0 0 100 10 100 10 2 1 0 2 0 0
TIMESTAMP 2026.01.08.09.08.44
"Default Font"
"Default Font"
0 0 0 0 94 6 0 "Regular default"
PART-TYPE
0 0 0 0 11 10 0 "Regular Arial"
REF-DES
CLOSED 5 10 255
-100 40
100 40
100 -40
-100 -40
-100 40
T200 0 0 1 50 10 0 4 110 -30 0 0 PIN
P-100 0 0 1 0 0 0 0 128
T-200 0 0 0 50 10 0 4 110 -30 0 0 PIN
P-100 0 0 1 0 0 0 0 128
螺丝孔 0 0 100 10 100 10 2 6 0 1 0 0
TIMESTAMP 2026.01.08.09.08.44
"Default Font"
"Default Font"
0 0 0 0 94 6 0 "Regular default"
PART-TYPE
0 0 0 0 94 6 0 "Regular default"
REF-DES
OPEN 2 10 255
50 80
-50 40
OPEN 2 10 255
50 40
-50 -10
OPEN 2 10 255
50 -10
-50 -60
OPEN 2 10 255
100 80
-100 80
OPEN 5 10 255
50 80
50 -60
0 -110
-50 -60
-50 80
OPEN 2 10 255
-100 80 1431 -1063 -125 -120 125 130
100 80
T0 -120 90 0 10 10 0 4 30 -30 0 0 PIN_3
P-100 0 0 1 0 0 0 0 128
Short-Symbol 0 0 100 10 100 10 2 1 0 2 0 0
TIMESTAMP 2026.01.08.09.08.44
"Default Font"
"Default Font"
0 0 0 0 94 6 0 "Regular default"
PART-TYPE
0 0 0 0 94 6 0 "Regular default"
REF-DES
CLOSED 5 10 255
-50 0
0 30
50 0
0 -30
-50 0
T100 0 0 1 25 10 0 4 60 -30 0 0 PIN_4
P-100 0 0 1 0 0 0 0 128
T-100 0 0 0 25 10 0 4 60 -30 0 0 PIN_4
P-100 0 0 1 0 0 0 0 128
LESD5D5.0CT1G 0 0 100 10 100 10 2 3 0 2 0 0
TIMESTAMP 2026.01.08.09.08.44
"Default Font"
"Default Font"
0 0 0 0 94 6 0 "Regular default"
PART-TYPE
0 0 0 0 11 10 0 "Regular Arial"
REF-DES
CLOSED 6 10 255
-100 50
0 0
0 0
-100 -50
-100 -50
-100 50
CLOSED 6 10 255
100 50
0 0
0 0
100 -50
100 -50
100 50
OPEN 10 10 255
-20 60
-20 60
-20 60
0 60
0 60
0 -60
0 -60
20 -60
20 -60
20 -60
T200 0 0 1 50 10 0 4 110 -30 0 0 PIN
P-100 0 0 1 0 0 0 0 128
T-200 0 0 0 50 10 0 4 110 -30 0 0 PIN
P-100 0 0 1 0 0 0 0 128
*PARTTYPE*
PZ200V-11-06P UND 1 0 0 0
TIMESTAMP 2026.01.08.09.08.44
GATE 1 6 0
PZ200V-11-06P
GND 0 U GND
BOOT 0 U BOOT
EN 0 U EN
RXD 0 U RXD
TXD 0 U TXD
VCC 0 U VCC
ESP32-C3-WROOM-02-N4(4MB) UND 1 0 0 0
TIMESTAMP 2026.01.08.09.08.44
GATE 1 19 0
ESP32-C3-WROOM-02-N4(4MB)
19 0 U EP
18 0 U IO0
17 0 U IO1
16 0 U IO2
15 0 U IO3
14 0 U IO19
13 0 U IO18
12 0 U TXD
11 0 U RXD
10 0 U IO10
9 0 U GND
8 0 U IO9
7 0 U IO8
6 0 U IO7
5 0 U IO6
4 0 U IO5
3 0 U IO4
2 0 U EN
1 0 U 3V3
电阻 UND 1 0 0 0
TIMESTAMP 2026.01.08.09.08.44
GATE 1 2 0
电阻
2 0 U 2
1 0 U 1
CL10A105KO8NNNC UND 1 0 0 0
TIMESTAMP 2026.01.08.09.08.44
GATE 1 2 0
CL10A105KO8NNNC
1 0 U 1
2 0 U 2
CapAcitance UND 1 0 0 0
TIMESTAMP 2026.01.08.09.08.44
GATE 1 2 0
CapAcitance
1 0 U 1
2 0 U 2
ME6211C33M5G-N UND 1 0 0 0
TIMESTAMP 2026.01.08.09.08.44
GATE 1 5 0
ME6211C33M5G-N
1 0 U VIN
2 0 U VSS
3 0 U CE
4 0 U NC
5 0 U VOUT
CL21A106KAYNNNE UND 1 0 0 0
TIMESTAMP 2026.01.08.09.08.44
GATE 1 2 0
CL21A106KAYNNNE
2 0 U 2
1 0 U 1
TS-1088-AR02016 UND 1 0 0 0
TIMESTAMP 2026.01.08.09.08.44
GATE 1 2 0
TS-1088-AR02016
2 0 U 2
1 0 U 1
TP4056 UND 1 0 0 0
TIMESTAMP 2026.01.08.09.08.44
GATE 1 9 0
TP4056
1 0 U TEMP
2 0 U PROG
3 0 U GND
4 0 U VCC
5 0 U BAT
6 0 U STDBY#
7 0 U CHRG#
8 0 U CE
9 0 U EP
0603WAF1201T5E UND 1 0 0 0
TIMESTAMP 2026.01.08.09.08.44
GATE 1 2 0
0603WAF1201T5E
2 0 U 2
1 0 U 1
CL21A106KAYNNNE_1 UND 1 0 0 0
TIMESTAMP 2026.01.08.09.08.44
GATE 1 2 0
CL21A106KAYNNNE_1
2 0 U 2
1 0 U 1
HC-1.25-2PWT UND 1 0 0 0
TIMESTAMP 2026.01.08.09.08.44
GATE 1 4 0
HC-1.25-2PWT
1 0 U 1
2 0 U 2
3 0 U 3
4 0 U 4
RC0603FR-071KL UND 1 0 0 0
TIMESTAMP 2026.01.08.09.08.44
GATE 1 2 0
RC0603FR-071KL
2 0 U 2
1 0 U 1
XL-3227SURUGC UND 1 0 0 0
TIMESTAMP 2026.01.08.09.08.44
GATE 1 4 0
XL-3227SURUGC
1 0 U 1
2 0 U 2
4 0 U 4
3 0 U 3
TYPE-C_6P(073) UND 1 0 0 0
TIMESTAMP 2026.01.08.09.08.44
GATE 1 7 0
TYPE-C_6P(073)
7 0 U EH
A12 0 U GND
A9 0 U VBUS
A5 0 U CC1
B5 0 U CC2
B9 0 U VBUS
B12 0 U GND
MSK12C02G25-B UND 1 0 0 0
TIMESTAMP 2026.01.08.09.08.44
GATE 1 5 0
MSK12C02G25-B
1 0 U 1
2 0 U 2
3 0 U 3
4 0 U 4
5 0 U 5
DTA144EE_C2991974 UND 1 0 0 0
TIMESTAMP 2026.01.08.09.08.44
GATE 1 3 0
DTA144EE_C2991974
2 0 U GND
1 0 U IN
3 0 U OUT
2N7002T UND 1 0 0 0
TIMESTAMP 2026.01.08.09.08.44
GATE 1 3 0
2N7002T
3 0 U D
1 0 U G
2 0 U S
RT0603BRD0720KL UND 1 0 0 0
TIMESTAMP 2026.01.08.09.08.44
GATE 1 2 0
RT0603BRD0720KL
2 0 U 2
1 0 U 1
RT0603BRD0750KL UND 1 0 0 0
TIMESTAMP 2026.01.08.09.08.44
GATE 1 2 0
RT0603BRD0750KL
2 0 U 2
1 0 U 1
WAFER-SH1.0-6PWB UND 1 0 0 0
TIMESTAMP 2026.01.08.09.08.44
GATE 1 8 0
WAFER-SH1.0-6PWB
1 0 U 1
2 0 U 2
3 0 U 3
4 0 U 4
5 0 U 5
6 0 U 6
7 0 U 7
8 0 U 8
0603WAF1003T5E UND 1 0 0 0
TIMESTAMP 2026.01.08.09.08.44
GATE 1 2 0
0603WAF1003T5E
2 0 U 2
1 0 U 1
0603WAF5101T5E UND 1 0 0 0
TIMESTAMP 2026.01.08.09.08.44
GATE 1 2 0
0603WAF5101T5E
2 0 U 2
1 0 U 1
SI2301_C2891731 UND 1 0 0 0
TIMESTAMP 2026.01.08.09.08.44
GATE 1 3 0
SI2301_C2891731
3 0 U D
1 0 U G
2 0 U S
S9013_C2891800 UND 1 0 0 0
TIMESTAMP 2026.01.08.09.08.44
GATE 1 3 0
S9013_C2891800
3 0 U C
1 0 U B
2 0 U E
0603WAF1002T5E UND 1 0 0 0
TIMESTAMP 2026.01.08.09.08.44
GATE 1 2 0
0603WAF1002T5E
2 0 U 2
1 0 U 1
螺丝孔 UND 1 0 0 0
TIMESTAMP 2026.01.08.09.08.44
GATE 1 1 0
螺丝孔
1 0 U 1
LESD5D5.0CT1G UND 1 0 0 0
TIMESTAMP 2026.01.08.09.08.44
GATE 1 2 0
LESD5D5.0CT1G
2 0 U 2
1 0 U 1
$PWR_SYMS UND 0 0 2 0
TIMESTAMP 2026.01.08.09.08.44
PWR 4
5-Voltage P 5-Voltage
Ground-GND P Ground-GND
GND P GND
B+ P B+
$OSR_SYMS UND 0 0 2 0
TIMESTAMP 2026.01.08.09.08.44
OFF 3
Netport-OUT U
Netport-IN U
VBUS U
*PART*
H1 PZ200V-11-06P 5315 7215 0 0 100 10 100 10 3 9 6 0 0 6
"Default Font"
"Default Font"
-100 350 0 0 111 10 1 "Regular Arial"
REF-DES
-550 -450 0 0 111 10 1 "Regular Arial"
PART-TYPE
-550 -450 0 0 111 10 1 "Regular Arial"
Name
"Footprint" 6PIN-2MM-UART
"Name" PZ200V-11-06P
"Device" 6PIN-2MM-UART
"Reuse Block" 
"Group ID" 
"Channel ID" 
"Unique ID" gge74
"Check" false
"Add into BOM" no
0 50 10 0 4
1 50 10 0 4
2 50 10 0 4
3 50 10 0 4
4 50 10 0 4
5 50 10 0 4
U1 ESP32-C3-WROOM-02-N4(4MB) 2665 7315 0 0 100 10 100 10 3 7 19 0 0 6
"Default Font"
"Default Font"
-50 400 0 0 111 10 1 "Regular Arial"
REF-DES
-500 -700 0 0 111 10 1 "Regular Arial"
PART-TYPE
-500 -700 0 0 111 10 1 "Regular Arial"
Name
"Symbol" ESP32-C3-WROOM-02-N4(4MB)
"Name" ESP32-C3-WROOM-02-N4
"Device" ESP32-C3-WROOM-02-N4
"Unique ID" gge75
"Reuse Block" 
"Group ID" 
"Channel ID" 
0 50 10 0 4
1 50 10 0 4
2 50 10 0 4
3 50 10 0 4
4 50 10 0 4
5 50 10 0 4
6 50 10 0 4
7 50 10 0 4
8 50 10 0 4
9 50 10 0 4
10 50 10 0 4
11 50 10 0 4
12 50 10 0 4
13 50 10 0 4
14 50 10 0 4
15 50 10 0 4
16 50 10 0 4
17 50 10 0 4
18 50 10 0 4
R1 电阻 965 7365 90 0 100 10 100 10 3 7 2 0 0 30
"Default Font"
"Default Font"
0 -100 90 3 111 10 1 "Regular Arial"
REF-DES
-100 -100 90 3 111 10 1 "Regular Arial"
PART-TYPE
-100 -100 90 3 111 10 1 "Regular Arial"
Name
"Symbol" 电阻
"Name" 10kΩ
"Device" 0603WAF1002T5E
"Unique ID" gge14_1
"Reuse Block" 
"Group ID" 
"Channel ID" 
0 50 10 0 4
1 50 10 0 4
C2 CL10A105KO8NNNC 965 7015 90 0 100 10 100 10 3 7 2 0 0 30
"Default Font"
"Default Font"
0 200 90 3 111 10 1 "Regular Arial"
REF-DES
-100 200 90 3 111 10 1 "Regular Arial"
PART-TYPE
-100 200 90 3 111 10 1 "Regular Arial"
Name
"Symbol" CL10A105KO8NNNC
"Name" 1uF
"Device" CL10A105KO8NNNC
"Unique ID" gge42_1
"Reuse Block" 
"Group ID" 
"Channel ID" 
0 50 10 0 4
1 50 10 0 4
C1 CapAcitance 565 7465 90 0 100 10 100 10 3 7 2 0 0 30
"Default Font"
"Default Font"
50 200 90 3 111 10 1 "Regular Arial"
REF-DES
-100 350 90 3 111 10 1 "Regular Arial"
PART-TYPE
-100 350 90 3 111 10 1 "Regular Arial"
Name
"Symbol" CapAcitance
"Name" 100nF
"Device" CL10B104KA8NNNC
"Unique ID" gge53
"Reuse Block" 
"Group ID" 
"Channel ID" 
0 50 10 0 4
1 50 10 0 4
U2 ME6211C33M5G-N 2615 5265 0 3 100 10 100 10 3 7 5 0 0 6
"Default Font"
"Default Font"
350 -250 0 0 111 10 1 "Regular Arial"
REF-DES
400 350 0 0 111 10 1 "Regular Arial"
PART-TYPE
400 350 0 0 111 10 1 "Regular Arial"
Name
"Symbol" ME6211C33M5G-N
"Name" ME6211C33M5G-N
"Device" ME6211C33M5G-N
"Unique ID" gge39
"Reuse Block" 
"Group ID" 
"Channel ID" 
0 50 10 0 4
1 50 10 0 4
2 50 10 0 4
3 50 10 0 4
4 50 10 0 4
C4 CL21A106KAYNNNE 1765 4965 90 0 100 10 100 10 3 7 2 0 0 30
"Default Font"
"Default Font"
0 -150 90 3 111 10 1 "Regular Arial"
REF-DES
-100 -150 90 3 111 10 1 "Regular Arial"
PART-TYPE
-100 -150 90 3 111 10 1 "Regular Arial"
Name
"Symbol" CL21A106KAYNNNE
"Name" 1uF
"Device" CL10A105KO8NNNC
"Unique ID" gge41
"Reuse Block" 
"Group ID" 
"Channel ID" 
0 50 10 0 4
1 50 10 0 4
C3 CL21A106KAYNNNE 3665 5365 0 3 100 10 100 10 3 7 2 0 0 30
"Default Font"
"Default Font"
200 -100 0 0 111 10 1 "Regular Arial"
REF-DES
0 -100 0 0 111 10 1 "Regular Arial"
PART-TYPE
0 -100 0 0 111 10 1 "Regular Arial"
Name
"Symbol" CL21A106KAYNNNE
"Name" 10uF
"Device" CL10A106KP8NNNC
"Unique ID" gge40
"Reuse Block" 
"Group ID" 
"Channel ID" 
0 50 10 0 4
1 50 10 0 4
R2 电阻 1315 7065 0 3 100 10 100 10 3 7 2 0 0 30
"Default Font"
"Default Font"
100 150 0 0 111 10 1 "Regular Arial"
REF-DES
100 50 0 0 111 10 1 "Regular Arial"
PART-TYPE
100 50 0 0 111 10 1 "Regular Arial"
Name
"Symbol" 电阻
"Name" 10kΩ
"Device" 0603WAF1002T5E
"Unique ID" gge14_2
"Reuse Block" 
"Group ID" 
"Channel ID" 
0 50 10 0 4
1 50 10 0 4
SW1 TS-1088-AR02016 7715 3515 0 0 100 10 100 10 3 7 2 0 0 14
"Default Font"
"Default Font"
-100 200 0 0 111 10 1 "Regular Arial"
REF-DES
-400 -150 0 0 111 10 1 "Regular Arial"
PART-TYPE
-400 -150 0 0 111 10 1 "Regular Arial"
Name
"Symbol" TS-1088-AR02016
"Name" TS-1088-AR02016
"Device" TS-1088-AR02016
"Unique ID" gge76
"Reuse Block" 
"Group ID" 
"Channel ID" 
0 50 10 0 4
1 50 10 0 4
U3 TP4056 2845 2975 0 0 100 10 100 10 3 11 9 0 0 6
"Default Font"
"Default Font"
-50 364 0 0 111 10 1 "Regular Arial"
REF-DES
-380 -390 0 0 111 10 1 "Regular Arial"
PART-TYPE
-380 -390 0 0 111 10 1 "Regular Arial"
Name
"Footprint" ESOP-8_L4.9-W3.9-P1.27-LS6.0-BL-EP
"Origin Footprint" ESOP-8_L4.9-W3.9-P1.27-LS6.0-BL-EP
"Unique ID" gge7da8da7d8345e91b
"Device" TP4056-42-ESOP8
"Symbol" TP4056
"Name" TP4056-42-ESOP8
"Convert to PCB" yes
"Add into BOM" yes
"Reuse Block" 
"Group ID" 
"Channel ID" 
0 50 10 0 4
1 50 10 0 4
2 50 10 0 4
3 50 10 0 4
4 50 10 0 4
5 50 10 0 4
6 50 10 0 4
7 50 10 0 4
8 50 10 0 4
R6 0603WAF1201T5E 2145 2975 0 0 100 10 100 10 3 16 2 0 0 30
"Default Font"
"Default Font"
-60 53 0 0 111 10 1 "Regular Arial"
REF-DES
-88 -46 0 0 111 10 1 "Regular Arial"
PART-TYPE
-88 -46 0 0 111 10 1 "Regular Arial"
Name
"Supplier Part" C22940
"Supplier" LCSC
"Manufacturer Part" 0603WAF2401T5E
"Footprint" R0603
"Unique ID" gge6fdc97697ec0b284
"Device" 0603WAF2401T5E
"Symbol" 0603WAF1201T5E
"Name" 2.4kΩ
"Convert to PCB" yes
"Add into BOM" yes
"Manufacturer" UNI-ROYAL(厚声)
"JLCPCB Part Class" Basic Part
"Value" 2.4kΩ
"Reuse Block" 
"Group ID" 
"Channel ID" 
0 50 10 0 4
1 50 10 0 4
C5 CL21A106KAYNNNE_1 2854 2525 0 3 100 10 100 10 3 11 2 0 0 30
"Default Font"
"Default Font"
170 126 0 0 111 10 1 "Regular Arial"
REF-DES
-42 126 0 0 111 10 1 "Regular Arial"
PART-TYPE
-42 126 0 0 111 10 1 "Regular Arial"
Name
"Footprint" C0603
"Origin Footprint" C0603
"Unique ID" gge246555bc41fdc801
"Device" CL10A106KP8NNNC
"Symbol" CL21A106KAYNNNE
"Name" 10uF
"Convert to PCB" yes
"Add into BOM" yes
"Reuse Block" 
"Group ID" 
"Channel ID" 
0 50 10 0 4
1 50 10 0 4
CN2 HC-1.25-2PWT 4215 1265 90 0 100 10 100 10 3 10 4 0 0 6
"Default Font"
"Default Font"
200 410 90 3 111 10 1 "Regular Arial"
REF-DES
200 160 90 3 111 10 1 "Regular Arial"
PART-TYPE
200 160 90 3 111 10 1 "Regular Arial"
Name
"Footprint" CONN-SMD_2P-P1.25-HC-1.25-2PWT
"Unique ID" gge79
"Device" HC-1.25-2PWT
"Symbol" HC-1.25-2PWT
"Name" HC-1.25-2PWT
"Convert to PCB" yes
"Add into BOM" yes
"Reuse Block" 
"Group ID" 
"Channel ID" 
0 50 10 0 4
1 50 10 0 4
2 50 10 0 4
3 50 10 0 4
R7 RC0603FR-071KL 3705 2975 0 3 100 10 100 10 3 13 2 0 0 30
"Default Font"
"Default Font"
110 -60 0 0 111 10 1 "Regular Arial"
REF-DES
110 140 0 0 111 10 1 "Regular Arial"
PART-TYPE
110 140 0 0 111 10 1 "Regular Arial"
Name
"LCSC Part Name" 1kΩ ±1% 100mW 厚膜电阻
"JLCPCB Part Class" Basic Part
"Description" 电阻类型:厚膜电阻;阻值:1kΩ;精度:±1%;功率:100mW;最大工作电压:75V;温度系数:±100ppm/℃;
"Footprint" R0603
"Unique ID" ggeda0f7288a491d0d7
"Device" 0603WAF1001T5E
"Symbol" RC0603FR-071KL
"Name" 1kΩ
"Convert to PCB" yes
"Add into BOM" yes
"Reuse Block" 
"Group ID" 
"Channel ID" 
0 50 10 0 4
1 50 10 0 4
R8 RC0603FR-071KL 3895 2874 0 3 100 10 100 10 3 13 2 0 0 30
"Default Font"
"Default Font"
110 -60 0 0 111 10 1 "Regular Arial"
REF-DES
110 140 0 0 111 10 1 "Regular Arial"
PART-TYPE
110 140 0 0 111 10 1 "Regular Arial"
Name
"LCSC Part Name" 1kΩ ±1% 100mW 厚膜电阻
"JLCPCB Part Class" Basic Part
"Description" 电阻类型:厚膜电阻;阻值:1kΩ;精度:±1%;功率:100mW;最大工作电压:75V;温度系数:±100ppm/℃;
"Footprint" R0603
"Unique ID" gge17
"Device" 0603WAF1001T5E
"Symbol" RC0603FR-071KL
"Name" 1kΩ
"Convert to PCB" yes
"Add into BOM" yes
"Reuse Block" 
"Group ID" 
"Channel ID" 
0 50 10 0 4
1 50 10 0 4
LED1 XL-3227SURUGC 4065 3365 90 0 100 10 100 10 3 17 4 0 0 30
"Default Font"
"Default Font"
-50 -200 90 3 111 10 1 "Regular Arial"
REF-DES
-100 -200 90 3 70 10 1 "Regular Arial"
PART-TYPE
-100 -200 90 3 70 10 1 "Regular Arial"
Name
"LCSC Part Name" 红翠绿双色贴片式发光二极管
"Supplier Footprint" SMD-4P,3.2x2.7mm
"Datasheet" https://item.szlcsc.com/datasheet/XL-3227SURUGC/1051451.html
"Description" 发光颜色:红色,翠绿色;正向压降(Vf):2.4V；3.4V;功率:70mW；50mW;正向电流:20mA;波长:520nm~530nm；620nm~630nm;二极管配置:共阳极;透镜颜色:无色透明透镜;色温:-;发光强度:78mcd；280mcd;发光角度:120°;载带方式:正贴;工作温度:-;
"Footprint" LED-SMD_4P-L3.2-W2.7-TL
"Unique ID" ggee51f8b9589fe0dc7
"Device" XL-3227SURUGC
"Symbol" XL-3227SURUGC
"Name" XL-3227SURUGC
"Convert to PCB" yes
"Add into BOM" yes
"Illumination Color" 红色,翠绿色
"Voltage - Forward(Vf)" 2.4V；3.4V
"Power(Watts)" 70mW；50mW
"Wavelength - Dominant" 520nm~530nm；620nm~630nm
"Mounting Style" 正贴
"Operating Temperature" -20℃~+85℃
0 75 10 0 4
1 75 10 0 4
2 75 10 0 4
3 75 10 0 4
USB1 TYPE-C_6P(073) 2565 1415 0 0 100 10 100 10 2 12 7 0 0 6
"Default Font"
"Default Font"
-300 400 0 0 111 10 1 "Regular Arial"
REF-DES
0 0 0 0 94 6 1 "Regular default"
PART-TYPE
"Symbol" TYPE-C 6P(073)
"Footprint" TYPE-C-SMD_TYPE-C-6P_5
"Device" TYPE-C 6P(073)
"Unique ID" gge1_1
"Supplier Part" C668623
"Manufacturer" SHOU HAN(首韩)
"Manufacturer Part" TYPE-C 6P(073)
"JLCPCB Part Class" Extended Part
"Supplier" LCSC
"Reuse Block" 
"Group ID" 
"Channel ID" 
0 100 10 0 4
1 100 10 0 4
2 100 10 0 4
3 100 10 0 4
4 100 10 0 4
5 100 10 0 4
6 100 10 0 4
SW2 MSK12C02G25-B 7465 2365 0 0 100 10 100 10 3 7 5 0 0 14
"Default Font"
"Default Font"
-550 0 0 0 111 10 1 "Regular Arial"
REF-DES
-850 -450 0 0 111 10 1 "Regular Arial"
PART-TYPE
-850 -450 0 0 111 10 1 "Regular Arial"
Name
"Symbol" MSK12C02G25-B
"Name" MSK12C02G25-B
"Device" MSK12C02G25-B
"Unique ID" gge76_1
"Reuse Block" 
"Group ID" 
"Channel ID" 
0 100 10 0 4
1 100 10 0 4
2 100 10 0 4
3 100 10 0 4
4 100 10 0 4
Q3 DTA144EE_C2991974 10365 3165 0 2 100 10 100 10 3 8 3 0 0 14
"Default Font"
"Default Font"
350 -50 0 0 111 10 1 "Regular Arial"
REF-DES
350 50 0 0 111 10 1 "Regular Arial"
PART-TYPE
350 50 0 0 111 10 1 "Regular Arial"
Name
"Symbol" DTA144EE_C2991974
"Name" DTA144EE
"Device" DTA144EE_C2991974
"Unique ID" gge60
"Reuse Block" 
"Group ID" 
"Channel ID" 
"引脚" 
0 100 10 0 4
1 100 10 0 4
2 100 10 0 4
Q4 2N7002T 9465 2865 0 0 100 10 100 10 3 26 3 0 0 30
"Default Font"
"Default Font"
300 50 0 0 111 10 1 "Regular Arial"
REF-DES
250 -150 0 0 111 10 1 "Regular Arial"
PART-TYPE
250 -150 0 0 111 10 1 "Regular Arial"
Name
"Symbol" 2N7002T
"Device" 2N7002T_C40106
"Name" 2N7002T
"Unique ID" gge61
"Reuse Block" 
"Group ID" 
"Channel ID" 
"LCSC Part Name" 1个N沟道 耐压:60V 电流:115mA
"Supplier Part" C40106
"Manufacturer" CJ(江苏长电/长晶)
"Manufacturer Part" 2N7002T
"Supplier Footprint" SC-75(SOT-523)
"JLCPCB Part Class" Extended Part
"Datasheet" https://atta.szlcsc.com/upload/public/pdf/source/20141219/1457707256656.pdf
"Supplier" LCSC
"Footprint" SC-75-3_L1.6-W0.8-P1.00-LS1.7-BR
"3D Model" c91d337f73514bed9e4f5de3964a5f78
"3D Model Title" SC-75-3_L1.6-W0.8-H0.9-LS1.6-P1.0
"3D Model Transform" 63.48633,62.992,0,180,0,0,0,0.005,0
"Type" 1个N沟道
"Drain to Source Voltage" 60V
"Current - Continuous Drain(Id)" 115mA
"RDS(on)" 7.5Ω@5V,50mA
"Pd - Power Dissipation" -
"Gate Threshold Voltage (Vgs(th)@Id)" -
"Description" 类型:1个N沟道;漏源电压(Vdss):60V;连续漏极电流(Id):115mA;导通电阻(RDS(on)):7.5Ω@5V,50mA;耗散功率(Pd):-;阈值电压(Vgs(th)):-;
0 50 10 0 4
1 50 10 0 4
2 50 10 0 4
R9 RT0603BRD0720KL 10665 2615 90 0 100 10 100 10 3 4 2 0 0 30
"Default Font"
"Default Font"
0 -100 90 3 111 10 1 "Regular Arial"
REF-DES
-100 -100 90 3 111 10 1 "Regular Arial"
PART-TYPE
-100 -100 90 3 111 10 1 "Regular Arial"
Name
"Symbol" RT0603BRD0720KL
"Name" 51kΩ
"Device" RT0603BRD0751KL
"Unique ID" gge58
0 50 10 0 4
1 50 10 0 4
R10 RT0603BRD0750KL 10665 2065 90 0 100 10 100 10 3 7 2 0 0 30
"Default Font"
"Default Font"
0 -100 90 3 111 10 1 "Regular Arial"
REF-DES
-100 -100 90 3 111 10 1 "Regular Arial"
PART-TYPE
-100 -100 90 3 111 10 1 "Regular Arial"
Name
"Symbol" RT0603BRD0750KL
"Name" 51kΩ
"Device" RT0603BRD0751KL
"Unique ID" gge59
"Reuse Block" 
"Group ID" 
"Channel ID" 
0 50 10 0 4
1 50 10 0 4
C6 CL21A106KAYNNNE 11065 2165 90 0 100 10 100 10 3 7 2 0 0 30
"Default Font"
"Default Font"
0 -150 90 3 111 10 1 "Regular Arial"
REF-DES
-100 -150 90 3 111 10 1 "Regular Arial"
PART-TYPE
-100 -150 90 3 111 10 1 "Regular Arial"
Name
"Symbol" CL21A106KAYNNNE
"Name" 100nF
"Device" CL10B104KA8NNNC
"Unique ID" gge43_1
"Reuse Block" 
"Group ID" 
"Channel ID" 
0 50 10 0 4
1 50 10 0 4
CN1 WAFER-SH1.0-6PWB 10815 6515 0 0 100 10 100 10 3 10 8 0 0 6
"Default Font"
"Default Font"
-300 400 0 0 111 10 1 "Regular Arial"
REF-DES
-700 -850 0 0 111 10 1 "Regular Arial"
PART-TYPE
-700 -850 0 0 111 10 1 "Regular Arial"
Name
"Footprint" CONN-SMD_6P-P1.00_MEGASTAR_ZX-SH1.0-6PWT
"Unique ID" gge79_1
"Device" ZX-SH1.0-6PWT
"Symbol" WAFER-SH1.0-6PWB
"Name" ZX-SH1.0-6PWT
"Convert to PCB" yes
"Add into BOM" yes
"Reuse Block" 
"Group ID" 
"Channel ID" 
0 50 10 0 4
1 50 10 0 4
2 50 10 0 4
3 50 10 0 4
4 50 10 0 4
5 50 10 0 4
6 50 10 0 4
7 50 10 0 4
R3 0603WAF1003T5E 7115 6615 90 3 100 10 100 10 3 10 2 0 0 30
"Default Font"
"Default Font"
30 110 90 0 111 10 1 "Regular Arial"
REF-DES
130 110 90 0 111 10 1 "Regular Arial"
PART-TYPE
130 110 90 0 111 10 1 "Regular Arial"
Name
"Footprint" R0603
"Unique ID" gge17_1
"Device" 0603WAF1003T5E
"Symbol" 0603WAF1003T5E
"Name" 100kΩ
"Convert to PCB" yes
"Add into BOM" yes
"Reuse Block" 
"Group ID" 
"Channel ID" 
0 50 10 0 4
1 50 10 0 4
R11 0603WAF5101T5E 315 1015 90 3 100 10 100 10 3 10 2 0 0 30
"Default Font"
"Default Font"
30 60 90 0 111 10 1 "Regular Arial"
REF-DES
130 60 90 0 111 10 1 "Regular Arial"
PART-TYPE
130 60 90 0 111 10 1 "Regular Arial"
Name
"Footprint" R0603
"Unique ID" gge17_2
"Device" 0603WAF5101T5E
"Symbol" 0603WAF5101T5E
"Name" 5.1kΩ
"Convert to PCB" yes
"Add into BOM" yes
"Reuse Block" 
"Group ID" 
"Channel ID" 
0 50 10 0 4
1 50 10 0 4
R12 0603WAF5101T5E 915 1015 90 3 100 10 100 10 3 10 2 0 0 30
"Default Font"
"Default Font"
30 60 90 0 111 10 1 "Regular Arial"
REF-DES
150 50 90 0 111 10 1 "Regular Arial"
PART-TYPE
150 50 90 0 111 10 1 "Regular Arial"
Name
"Footprint" R0603
"Unique ID" gge17_3
"Device" 0603WAF5101T5E
"Symbol" 0603WAF5101T5E
"Name" 5.1kΩ
"Convert to PCB" yes
"Add into BOM" yes
"Reuse Block" 
"Group ID" 
"Channel ID" 
0 50 10 0 4
1 50 10 0 4
Q1 SI2301_C2891731 7765 6815 90 1 100 10 100 10 3 7 3 0 0 22
"Default Font"
"Default Font"
150 -100 90 0 111 10 1 "Regular Arial"
REF-DES
-400 -100 90 0 111 10 1 "Regular Arial"
PART-TYPE
-400 -100 90 0 111 10 1 "Regular Arial"
Name
"Symbol" SI2301_C2891731
"Device" SI2301_C2891731
"Name" SI2301
"Unique ID" gge80
"Reuse Block" 
"Group ID" 
"Channel ID" 
0 50 10 0 4
1 50 10 0 4
2 50 10 0 4
Q2 S9013_C2891800 7665 6015 0 0 100 10 100 10 3 7 3 0 0 30
"Default Font"
"Default Font"
200 200 0 0 111 10 1 "Regular Arial"
REF-DES
200 60 0 0 111 10 1 "Regular Arial"
PART-TYPE
200 60 0 0 111 10 1 "Regular Arial"
Name
"Symbol" S9013_C2891800
"Name" S9013
"Device" S9013_C2891800
"Unique ID" gge81
"Reuse Block" 
"Group ID" 
"Channel ID" 
0 50 10 0 4
1 50 10 0 4
2 50 10 0 4
R4 0603WAF1002T5E 6815 6015 0 0 100 10 100 10 3 13 2 0 0 30
"Default Font"
"Default Font"
-100 50 0 0 111 10 1 "Regular Arial"
REF-DES
-100 -150 0 0 111 10 1 "Regular Arial"
PART-TYPE
-100 -150 0 0 111 10 1 "Regular Arial"
Name
"Description" 电阻类型:厚膜电阻;阻值:10kΩ;精度:±1%;功率:100mW;工作电压:75V;温度系数:±100ppm/℃;
"Footprint" R0603
"Unique ID" gge17_4
"Device" 0603WAF1002T5E
"Symbol" 0603WAF1002T5E
"Name" 10kΩ
"Convert to PCB" yes
"Add into BOM" yes
"Voltage-Supply(Max)" 75V
"Operating Temperature" -55℃~+155℃
"Reuse Block" 
"Group ID" 
"Channel ID" 
0 50 10 0 4
1 50 10 0 4
R5 0603WAF1002T5E 7115 5815 90 0 100 10 100 10 3 13 2 0 0 30
"Default Font"
"Default Font"
0 -100 90 3 111 10 1 "Regular Arial"
REF-DES
-100 -100 90 3 111 10 1 "Regular Arial"
PART-TYPE
-100 -100 90 3 111 10 1 "Regular Arial"
Name
"Description" 电阻类型:厚膜电阻;阻值:10kΩ;精度:±1%;功率:100mW;工作电压:75V;温度系数:±100ppm/℃;
"Footprint" R0603
"Unique ID" gge17_5
"Device" 0603WAF1002T5E
"Symbol" 0603WAF1002T5E
"Name" 10kΩ
"Convert to PCB" yes
"Add into BOM" yes
"Voltage-Supply(Max)" 75V
"Operating Temperature" -55℃~+155℃
"Reuse Block" 
"Group ID" 
"Channel ID" 
0 50 10 0 4
1 50 10 0 4
SCREW1 螺丝孔 5315 1635 0 0 100 10 100 10 3 6 1 0 0 30
"Default Font"
"Default Font"
-200 -270 0 0 111 10 1 "Regular Arial"
REF-DES
150 10 0 0 111 10 1 "Regular Arial"
PART-TYPE
150 10 0 0 111 10 1 "Regular Arial"
Name
"Name" 
"Device" M2螺丝
"Reuse Block" 
"Group ID" 
"Channel ID" 
"Unique ID" gge82
0 10 10 0 4
SCREW2 螺丝孔 5865 1635 0 0 100 10 100 10 3 6 1 0 0 30
"Default Font"
"Default Font"
-200 -270 0 0 111 10 1 "Regular Arial"
REF-DES
150 10 0 0 111 10 1 "Regular Arial"
PART-TYPE
150 10 0 0 111 10 1 "Regular Arial"
Name
"Name" 
"Device" M2螺丝
"Reuse Block" 
"Group ID" 
"Channel ID" 
"Unique ID" gge83
0 10 10 0 4
SCREW3 螺丝孔 5315 1035 0 0 100 10 100 10 3 6 1 0 0 30
"Default Font"
"Default Font"
-200 -270 0 0 111 10 1 "Regular Arial"
REF-DES
150 10 0 0 111 10 1 "Regular Arial"
PART-TYPE
150 10 0 0 111 10 1 "Regular Arial"
Name
"Name" 
"Device" M2螺丝
"Reuse Block" 
"Group ID" 
"Channel ID" 
"Unique ID" gge84
0 10 10 0 4
D2 LESD5D5.0CT1G 1265 1015 90 3 100 10 100 10 2 6 2 0 0 30
"Default Font"
"Default Font"
0 80 90 0 111 10 1 "Regular Arial"
REF-DES
100 149 90 0 111 10 1 "Regular Arial"
PART-TYPE
"Name" LESD5D5.0CT1G
"Device" LESD5D5.0CT1G
"Unique ID" gge21
"Reuse Block" 
"Group ID" 
"Channel ID" 
0 50 10 0 4
1 50 10 0 4
D1 LESD5D5.0CT1G 665 1015 90 3 100 10 100 10 2 6 2 0 0 30
"Default Font"
"Default Font"
0 50 90 0 111 10 1 "Regular Arial"
REF-DES
100 149 90 0 111 10 1 "Regular Arial"
PART-TYPE
"Name" LESD5D5.0CT1G
"Device" LESD5D5.0CT1G
"Unique ID" gge11
"Reuse Block" 
"Group ID" 
"Channel ID" 
0 50 10 0 4
1 50 10 0 4
D3 LESD5D5.0CT1G 1815 1015 90 3 100 10 100 10 2 6 2 0 0 30
"Default Font"
"Default Font"
0 100 90 0 111 10 1 "Regular Arial"
REF-DES
100 149 90 0 111 10 1 "Regular Arial"
PART-TYPE
"Name" LESD5D5.0CT1G
"Device" LESD5D5.0CT1G
"Unique ID" gge32
"Reuse Block" 
"Group ID" 
"Channel ID" 
0 50 10 0 4
1 50 10 0 4
*BUSSES*
*OFFPAGE REFS*
@@@O0 +3.3V $PWR_SYMS 565 7665 0 0 0
@@@O1 GND $PWR_SYMS 565 6865 0 0 1
@@@O2 +3.3V $PWR_SYMS 4615 6965 0 0 0
@@@O3 GND $PWR_SYMS 4665 7465 90 3 1
@@@O4 GND $PWR_SYMS 2065 6865 0 0 1
@@@O5 GND $PWR_SYMS 4065 7765 0 0 1
@@@O6 FP_TX $OSR_SYMS 3065 7465 0 0 0
@@@O7 FP_RX $OSR_SYMS 3065 7365 0 0 0
@@@O8 +3.3V $PWR_SYMS 1765 5215 0 0 0
@@@O9 GND $PWR_SYMS 1765 4815 0 0 1
@@@O10 GND $PWR_SYMS 3815 5365 90 0 1
@@@O11 GND $PWR_SYMS 3115 5265 90 0 1
@@@O12 VIN $OSR_SYMS 3515 5165 0 3 1
@@@O13 BAT_ADC $OSR_SYMS 3065 7565 0 0 0
@@@O14 BAT_TEST $OSR_SYMS 3065 7665 0 0 0
@@@O15 +3.3V $PWR_SYMS 1115 6965 0 3 0
@@@O16 GND $PWR_SYMS 8215 3515 90 0 1
@@@O17 BTN-PAIR $OSR_SYMS 7265 3515 0 0 1
@@@O18 VBUS $OSR_SYMS 1965 1515 0 0 2
@@@O19 GND $PWR_SYMS 1815 715 0 0 2
@@@O20 GND $PWR_SYMS 1765 1665 0 3 2
@@@O21 VBUS $OSR_SYMS 1765 1215 0 0 2
@@@O22 GND $PWR_SYMS 3065 1415 0 0 2
@@@O23 BAT+ $PWR_SYMS 3345 2525 90 3 3
@@@O24 GND $PWR_SYMS 1945 2725 0 0 2
@@@O25 VBUS $OSR_SYMS 3465 3665 90 3 2
@@@O26 BAT+ $PWR_SYMS 4355 965 0 3 3
@@@O27 GND $PWR_SYMS 4085 965 0 0 2
@@@O28 BAT+ $PWR_SYMS 7265 2765 90 0 3
@@@O29 GND $PWR_SYMS 7865 2265 90 0 1
@@@O30 VIN $OSR_SYMS 7565 2765 0 3 1
@@@O31 GND $PWR_SYMS 6965 2265 90 3 1
@@@O32 BAT_ADC $OSR_SYMS 11115 2365 0 3 1
@@@O33 BAT_TEST $OSR_SYMS 9265 2865 0 0 1
@@@O34 GND $PWR_SYMS 10665 1915 0 0 1
@@@O35 GND $PWR_SYMS 9565 2665 0 0 1
@@@O36 VIN $OSR_SYMS 10665 3515 0 0 1
@@@O37 +3.3V $PWR_SYMS 7115 7015 0 0 0
@@@O38 FP_VCC $OSR_SYMS 8165 6815 0 0 0
@@@O39 FP_VCC $OSR_SYMS 10615 6465 0 0 1
@@@O40 FP_V_SENSOR $OSR_SYMS 10615 6265 0 0 1
@@@O41 FP_TOUCH_OUT $OSR_SYMS 10615 6365 0 0 1
@@@O42 FP_TX $OSR_SYMS 10615 6565 0 0 1
@@@O43 FP_RX $OSR_SYMS 10615 6665 0 0 1
@@@O44 GND $PWR_SYMS 10865 6065 0 0 2
@@@O45 FP_ENABLE $OSR_SYMS 6665 6015 0 0 1
@@@O46 GND $PWR_SYMS 7765 5365 0 0 2
@@@O47 FP_TOUCH_OUT $OSR_SYMS 3065 7265 0 0 0
@@@O48 FP_V_SENSOR $OSR_SYMS 10365 4915 0 0 1
@@@O49 +3.3V $PWR_SYMS 10765 4915 0 0 0
@@@O50 FP_ENABLE $OSR_SYMS 3065 6865 0 3 1
@@@O51 BTN-PAIR $OSR_SYMS 2265 7165 0 0 1
@@@O52 BOOT @TERM 1915 6965 0 0 -2
@@@O53 RXD @TERM 3365 6965 0 0 -2
@@@O54 TXD @TERM 3365 7065 0 0 -2
@@@O55 TXD @TERM 4815 7065 0 0 -2
@@@O56 RXD @TERM 4815 7165 0 0 -2
@@@O57 BOOT @TERM 4815 7365 0 0 -2
@@@O58 EN @TERM 4815 7265 0 0 -2
*TIEDOTS*
@@@D0 3465 3565
@@@D1 3345 3075
@@@D2 3965 3565
@@@D3 10865 6965
@@@D4 10865 6065
@@@D5 7115 6815
@@@D6 1815 715
@@@D7 1815 715
@@@D8 1265 715
@@@D9 915 715
@@@D10 665 715
@@@D11 665 1415
@@@D12 7765 5515
@@@D13 7765 6315
@@@D14 1265 1315
@@@D15 11065 2365
@@@D16 10665 2365
@@@D17 10665 1915
@@@D18 1815 1215
@@@D19 1945 2875
@@@D20 1945 2975
@@@D21 2145 2875
@@@D22 1945 3075
@@@D23 3345 2525
@@@D24 965 7665
@@@D25 565 7665
@@@D26 565 6865
@@@D27 1765 5165
@@@D28 3465 5165
@@@D29 3465 5365
@@@D30 965 7165
@@@D31 7115 6015
*CONNECTION*
*SIGNAL* VBUS 0 0
@@@D1 U3.8 2 0
3345 3075
3345 3075
@@@D0 @@@D1 3 0
3465 3565
3465 3075
3345 3075
@@@D0 @@@O25 2 0
3465 3565
3465 3665
@@@D2 LED1.2 2 0
3965 3565
3965 3565
@@@D0 @@@D2 2 0
3465 3565
3965 3565
@@@D2 LED1.4 2 0
3965 3565
4165 3565
@@@D1 U3.4 5 0
3345 3075
2895 3075
2895 2725
2345 2725
2345 2775
USB1.B9 @@@O18 2 0
2065 1515
1965 1515
@@@D18 D3.1 2 0
1815 1215
1815 1215
@@@O21 @@@D18 2 0
1765 1215
1815 1215
USB1.A9 @@@D18 2 0
2065 1215
1815 1215
*SIGNAL* $$$1 0 0
LED1.1 R7.1 3 0
3965 3165
3965 2975
3905 2975
*SIGNAL* $$$2 0 0
LED1.3 R8.1 3 0
4165 3165
4165 2875
4095 2875
*SIGNAL* GND 0 0
@@@O35 Q4.2 2 0
9565 2665
9565 2665
@@@D3 CN1.8 2 0
10865 6965
10865 6965
@@@D4 @@@O44 2 0
10865 6065
10865 6065
@@@D4 CN1.7 2 0
10865 6065
10865 6065
@@@D3 @@@D4 4 0
10865 6965
11015 6965
11015 6065
10865 6065
CN1.1 @@@D3 3 0
10615 6765
10615 6965
10865 6965
@@@D6 @@@D7 2 0
1815 715
1815 715
@@@D6 @@@O19 2 0
1815 715
1815 715
@@@D6 USB1.A12 3 0
1815 715
2065 715
2065 1115
@@@D8 @@@D7 2 0
1265 715
1815 715
@@@D9 @@@D8 2 0
915 715
1265 715
@@@D10 @@@D9 2 0
665 715
915 715
R11.2 @@@D10 3 0
315 815
315 715
665 715
@@@D10 D1.2 2 0
665 715
665 815
@@@D9 R12.2 2 0
915 715
915 815
@@@D8 D2.2 2 0
1265 715
1265 815
D3.2 @@@D7 2 0
1815 815
1815 715
Q2.2 @@@D12 2 0
7765 5815
7765 5515
@@@D12 R5.1 3 0
7765 5515
7115 5515
7115 5615
@@@O46 @@@D12 2 0
7765 5365
7765 5515
@@@D17 @@@O34 2 0
10665 1915
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
@@@O31 SW2.5 2 0
6965 2265
6965 2265
@@@O29 SW2.4 2 0
7865 2265
7865 2265
SW1.2 @@@O16 2 0
8015 3515
8215 3515
USB1.7 @@@O22 2 0
3065 1415
3065 1415
USB1.B12 @@@O20 3 0
2065 1615
1765 1615
1765 1665
@@@D20 R6.1 2 0
1945 2975
1945 2975
@@@D19 @@@D20 2 0
1945 2875
1945 2975
@@@O24 @@@D19 2 0
1945 2725
1945 2875
@@@D21 @@@D19 2 0
2145 2875
1945 2875
C5.2 @@@D21 3 0
2655 2525
2145 2525
2145 2875
U3.3 @@@D21 2 0
2345 2875
2145 2875
@@@D20 @@@D22 2 0
1945 2975
1945 3075
@@@D22 U3.9 4 0
1945 3075
1945 3325
3345 3325
3345 3175
U3.1 @@@D22 2 0
2345 3075
1945 3075
@@@O27 CN2.2 3 0
4085 965
4165 965
4165 1065
@@@O11 U2.2 2 0
3115 5265
3115 5265
@@@D26 @@@O1 2 0
565 6865
565 6865
@@@D26 C1.1 2 0
565 6865
565 7265
@@@D26 C2.1 2 0
565 6865
965 6865
H1.GND @@@O3 2 0
5115 7465
4665 7465
U1.19 @@@O5 2 0
3065 7765
4065 7765
@@@O9 C4.1 2 0
1765 4815
1765 4765
@@@O10 C3.1 2 0
3815 5365
3865 5365
*SIGNAL* FP_RX 0 0
@@@O43 CN1.2 2 0
10615 6665
10615 6665
@@@O7 U1.15 2 0
3065 7365
3065 7365
*SIGNAL* FP_TX 0 0
@@@O42 CN1.3 2 0
10615 6565
10615 6565
@@@O6 U1.16 2 0
3065 7465
3065 7465
*SIGNAL* FP_TOUCH_OUT 0 0
@@@O41 CN1.5 2 0
10615 6365
10615 6365
@@@O47 U1.14 2 0
3065 7265
3065 7265
*SIGNAL* FP_V_SENSOR 0 0
CN1.6 @@@O40 2 0
10615 6265
10615 6265
*SIGNAL* FP_VCC 0 0
@@@O39 CN1.4 2 0
10615 6465
10615 6465
@@@O38 Q1.3 2 0
8165 6815
7965 6815
*SIGNAL* +3.3V 0 0
@@@D5 R3.1 2 0
7115 6815
7115 6815
@@@D5 @@@O37 2 0
7115 6815
7115 7015
Q1.2 @@@D5 2 0
7565 6815
7115 6815
@@@O48 @@@O49 2 0
10365 4915
10765 4915
@@@D25 @@@O0 2 0
565 7665
565 7665
@@@D25 C1.2 2 0
565 7665
565 7665
@@@D24 @@@D25 2 0
965 7665
565 7665
@@@D24 R1.2 2 0
965 7665
965 7565
@@@D24 U1.1 2 0
965 7665
2265 7665
H1.VCC @@@O2 2 0
5115 6965
4615 6965
@@@D27 C4.2 2 0
1765 5165
1765 5165
@@@D27 U2.5 2 0
1765 5165
2115 5165
@@@O8 @@@D27 2 0
1765 5215
1765 5165
@@@O15 R2.2 2 0
1115 6965
1115 7065
*SIGNAL* $$$3 0 0
@@@D11 R11.1 3 0
665 1415
315 1415
315 1215
@@@D11 D1.1 2 0
665 1415
665 1215
USB1.A5 @@@D11 2 0
2065 1415
665 1415
*SIGNAL* BTN-PAIR 0 0
@@@O51 U1.6 2 0
2265 7165
2265 7165
SW1.1 @@@O17 2 0
7415 3515
7265 3515
*SIGNAL* FP_ENABLE 0 0
U1.10 @@@O50 2 0
3065 6865
3065 6865
R4.1 @@@O45 2 0
6615 6015
6665 6015
*SIGNAL* $$$4 0 0
@@@D13 R3.2 3 0
7765 6315
7115 6315
7115 6415
Q2.3 @@@D13 2 0
7765 6215
7765 6315
Q1.1 @@@D13 2 0
7765 6565
7765 6315
*SIGNAL* $$$5 0 0
USB1.B5 @@@D14 2 0
2065 1315
1265 1315
@@@D14 R12.1 3 0
1265 1315
915 1315
915 1215
@@@D14 D2.1 2 0
1265 1315
1265 1215
*SIGNAL* BAT_ADC 0 0
@@@D15 C6.2 2 0
11065 2365
11065 2365
@@@D15 @@@O32 2 0
11065 2365
11115 2365
@@@D16 @@@D15 2 0
10665 2365
11065 2365
R9.1 @@@D16 2 0
10665 2415
10665 2365
R10.2 @@@D16 2 0
10665 2265
10665 2365
@@@O13 U1.17 2 0
3065 7565
3065 7565
*SIGNAL* VIN 0 0
@@@O36 Q3.2 2 0
10665 3515
10665 3515
SW2.2 @@@O30 3 0
7465 2665
7465 2765
7565 2765
U2.1 @@@D28 2 0
3115 5165
3465 5165
@@@D29 C3.2 2 0
3465 5365
3465 5365
@@@D28 @@@D29 2 0
3465 5165
3465 5365
U2.3 @@@D29 2 0
3115 5365
3465 5365
@@@O12 @@@D28 2 0
3515 5165
3465 5165
*SIGNAL* BAT_TEST 0 0
@@@O33 Q4.1 2 0
9265 2865
9265 2865
@@@O14 U1.18 2 0
3065 7665
3065 7665
*SIGNAL* BAT+ 0 0
@@@O28 SW2.1 2 0
7265 2765
7265 2665
@@@D23 @@@O23 2 0
3345 2525
3345 2525
C5.1 @@@D23 2 0
3055 2525
3345 2525
@@@D23 U3.5 2 0
3345 2525
3345 2775
@@@O26 CN2.1 3 0
4355 965
4265 965
4265 1065
*SIGNAL* BOOT 0 0
U1.8 @@@O52 2 0
2265 6965
1915 6965
H1.BOOT @@@O57 2 0
5115 7365
4815 7365
*SIGNAL* RXD 0 0
U1.11 @@@O53 2 0
3065 6965
3365 6965
H1.RXD @@@O56 2 0
5115 7165
4815 7165
*SIGNAL* TXD 0 0
U1.12 @@@O54 2 0
3065 7065
3365 7065
H1.TXD @@@O55 2 0
5115 7065
4815 7065
*SIGNAL* EN 0 0
H1.EN @@@O58 2 0
5115 7265
4815 7265
@@@D30 C2.2 2 0
965 7165
965 7165
@@@D30 R1.1 2 0
965 7165
965 7165
@@@D30 U1.2 4 0
965 7165
1315 7165
1315 7565
2265 7565
*SIGNAL* $$$6 0 0
U1.9 @@@O4 2 0
2265 6865
2065 6864
*SIGNAL* $$$7 0 0
R2.1 U1.7 2 0
1515 7065
2265 7065
*SIGNAL* $$$8 0 0
R6.2 U3.2 2 0
2345 2975
2345 2975
*SIGNAL* $$$9 0 0
U3.7 R7.2 2 0
3345 2975
3505 2975
*SIGNAL* $$$10 0 0
U3.6 R8.2 2 0
3345 2875
3695 2875
*SIGNAL* $$$11 0 0
R9.2 Q3.3 2 0
10665 2815
10665 2815
*SIGNAL* $$$12 0 0
Q4.3 Q3.1 3 0
9565 3065
9565 3115
10065 3115
*SIGNAL* $$$13 0 0
@@@D31 R5.2 2 0
7115 6015
7115 6015
Q2.1 @@@D31 2 0
7565 6015
7115 6015
@@@D31 R4.2 2 0
7115 6015
7015 6015
*NETNAMES*
+3.3V @@@O0 0 150 0 12 0      0      0 0 -1 10 97 "Regular DOUYU Font"
+3.3V @@@O2 0 150 0 12 0      0      0 0 -1 10 97 "Regular DOUYU Font"
FP_TX @@@O6 450 0 0 8 0      0      0 0 -1 10 97 "Regular DOUYU Font"
FP_RX @@@O7 450 0 0 8 0      0      0 0 -1 10 97 "Regular DOUYU Font"
+3.3V @@@O8 0 200 0 12 0      0      0 0 -1 10 97 "Regular DOUYU Font"
VIN @@@O12 -450 0 0 8 0      0      0 0 -1 10 97 "Regular DOUYU Font"
BAT_ADC @@@O13 450 0 0 8 0      0      0 0 -1 10 97 "Regular DOUYU Font"
BAT_TEST @@@O14 450 0 0 8 0      0      0 0 -1 10 97 "Regular DOUYU Font"
+3.3V @@@O15 0 150 0 12 0      0      0 0 -1 10 97 "Regular DOUYU Font"
BTN-PAIR @@@O17 -450 0 0 9 0      0      0 0 -1 10 97 "Regular DOUYU Font"
VBUS @@@O18 -210 59 0 3 0      0      0 0 -1 10 97 "Regular DOUYU Font"
GND @@@O19 -130 -297 0 0 0      0      0 0 -1 10 97 "Regular DOUYU Font"
GND @@@O20 130 297 0 3 0      0      0 0 -1 10 97 "Regular DOUYU Font"
VBUS @@@O21 -210 59 0 3 0      0      0 0 -1 10 97 "Regular DOUYU Font"
GND @@@O22 -130 -297 0 0 0      0      0 0 -1 10 97 "Regular DOUYU Font"
BAT+ @@@O23 132 -66 0 0 0      0      0 0 -1 10 97 "Regular DOUYU Font"
GND @@@O24 -130 -285 0 0 0      0      0 0 -1 10 97 "Regular DOUYU Font"
VBUS @@@O25 -139 192 0 0 0      0      0 0 -1 10 97 "Regular DOUYU Font"
BAT+ @@@O26 -75 -235 0 0 0      0      0 0 -1 10 97 "Regular DOUYU Font"
GND @@@O27 -130 -285 0 0 0      0      0 0 -1 10 97 "Regular DOUYU Font"
BAT+ @@@O28 -132 66 0 3 0      0      0 0 -1 10 97 "Regular DOUYU Font"
VIN @@@O30 -450 0 0 8 0      0      0 0 -1 10 97 "Regular DOUYU Font"
BAT_ADC @@@O32 100 100 0 8 0      0      0 0 -1 10 97 "Regular DOUYU Font"
BAT_TEST @@@O33 50 100 0 9 0      0      0 0 -1 10 97 "Regular DOUYU Font"
VIN @@@O36 -450 0 0 9 0      0      0 0 -1 10 97 "Regular DOUYU Font"
+3.3V @@@O37 0 200 0 12 0      0      0 0 -1 10 97 "Regular DOUYU Font"
FP_VCC @@@O38 450 0 0 8 0      0      0 0 -1 10 97 "Regular DOUYU Font"
FP_VCC @@@O39 -450 0 0 9 0      0      0 0 -1 10 97 "Regular DOUYU Font"
FP_V_SENSOR @@@O40 -450 0 0 9 0      0      0 0 -1 10 97 "Regular DOUYU Font"
FP_TOUCH_OUT @@@O41 -450 0 0 9 0      0      0 0 -1 10 97 "Regular DOUYU Font"
FP_TX @@@O42 -450 0 0 9 0      0      0 0 -1 10 97 "Regular DOUYU Font"
FP_RX @@@O43 -450 0 0 9 0      0      0 0 -1 10 97 "Regular DOUYU Font"
GND @@@O44 -130 -285 0 0 0      0      0 0 -1 10 97 "Regular DOUYU Font"
FP_ENABLE @@@O45 -450 0 0 9 0      0      0 0 -1 10 97 "Regular DOUYU Font"
GND @@@O46 -130 -285 0 0 0      0      0 0 -1 10 97 "Regular DOUYU Font"
FP_TOUCH_OUT @@@O47 450 0 0 8 0      0      0 0 -1 10 97 "Regular DOUYU Font"
FP_V_SENSOR @@@O48 -450 0 0 9 0      0      0 0 -1 10 97 "Regular DOUYU Font"
+3.3V @@@O49 0 200 0 12 0      0      0 0 -1 10 97 "Regular DOUYU Font"
FP_ENABLE @@@O50 450 -0 0 8 0      0      0 0 -1 10 97 "Regular DOUYU Font"
BTN-PAIR @@@O51 -450 0 0 9 0      0      0 0 -1 10 97 "Regular DOUYU Font"
BOOT U1.8 -300 0 0 0 0      0      0 0 -1 10 97 "Regular DOUYU Font"
RXD U1.11 100 0 0 0 0      0      0 0 -1 10 97 "Regular DOUYU Font"
TXD U1.12 100 0 0 0 0      0      0 0 -1 10 97 "Regular DOUYU Font"
TXD H1.TXD -300 0 0 0 0      0      0 0 -1 10 97 "Regular DOUYU Font"
RXD H1.RXD -300 0 0 0 0      0      0 0 -1 10 97 "Regular DOUYU Font"
BOOT H1.BOOT -300 0 0 0 0      0      0 0 -1 10 97 "Regular DOUYU Font"
EN H1.EN -300 0 0 0 0      0      0 0 -1 10 97 "Regular DOUYU Font"
EN U1.2 -950 -400 0 0 0      0      0 0 -1 10 97 "Regular DOUYU Font"

*END*

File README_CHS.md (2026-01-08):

# MYNOVA-Sparkin

[English](README.md) | [中文文档](README_CHS.md)

## 项目概述

MYNOVA-Sparkin 是一款用于 Windows 计算机的无线蓝牙指纹识别设备。它提供快速指纹识别（0.5秒）、本地指纹管理和系统登录集成功能。该项目包含完整的硬件设计、固件和 Windows 配套软件。

Sparkin Overview
Sparkin Overview
Sparkin Overview
Sparkin PCB1
Sparkin PCB2
Sparkin Overview

## 主要特性

- **快速识别**：0.5 秒指纹识别速度
- **无线连接**：蓝牙 BLE 5.0 稳定连接
- **系统集成**：指纹验证通过后自动登录 Windows
- **本地存储**：指纹安全存储在设备上
- **便携设计**：内置电池，支持 Type-C 充电
- **省电模式**：自动睡眠模式节省电量
- **OTA 更新**：支持在线固件更新（需要有服务器）

## 快速开始

### 前置条件

- 支持蓝牙的 Windows 10/11 计算机
- Type-C 充电线（用于设备初始充电）

### 安装

1. 从 [Releases](https://github.com/yourusername/MYNOVA-Sparkin/releases) 页面下载最新的 Windows 安装程序
2. 运行安装程序并按照屏幕说明操作
3. 安装完成后，Sparkin 服务将自动启动
4. 从开始菜单启动 Sparkin 配置客户端

### 设备配对

1. 按住配对按钮 3 秒，直到 LED 闪烁
2. 打开 Sparkin 配置客户端
3. 点击"添加设备"并选择"Sparkin FP01"
4. 按照说明完成配对

### 指纹录入

1. 确保设备已连接
2. 在客户端中进入"指纹管理"
3. 点击"录入新指纹"
4. 按照指示多次扫描指纹
5. 为指纹分配名称

### 系统登录设置

1. 在客户端中进入"登录设置"
2. 启用"使用指纹自动登录"
3. 输入 Windows 登录密码
4. 点击"保存"完成设置

## 项目结构

```
MYNOVA-Sparkin/
├── SparkinFW/          # 设备固件 (Arduino/ESP32-C3)
├── SparkinWin/         # Windows 应用程序和安装文件
├── 3DModels/           # 外壳 3D 模型
├── Labels/             # 标签贴纸设计文件
└── PCB/                # PCB 设计文件
```

### SparkinFW
基于 Arduino 框架的 ESP32-C3 设备固件，包含：
- 指纹传感器管理
- 蓝牙 BLE 通信
- 电源和电池管理
- 睡眠模式控制
- OTA 更新支持

### SparkinWin
Windows 配套应用程序：
- 蓝牙通信后台服务
- 设备管理配置客户端
- 指纹录入界面
- 系统登录集成

## 开发

### 固件开发

- **IDE**: Arduino IDE 2.3.6+
- **ESP32 核心**: 3.1.1+
- **语言**: C++

### Windows 应用开发

- **IDE**: Visual Studio 2022
- **框架**: Windows 10/11 SDK
- **语言**: C#/C++

## 文档

详细技术文档：
- [固件架构](docs/firmware-architecture.md)
- [Windows 应用指南](docs/windows-application.md)

## 贡献

欢迎贡献！请遵循以下步骤：

1. Fork 仓库
2. 创建特性分支
3. 提交更改
4. 提交拉取请求

## 版权声明

本项目禁止用于任何商业用途、仅供学习和自己DIY使用。

## 许可证 [LICENSE](LICENSE)

本项目采用[GPLv3](LICENSE)许可证。[GPLv3（GNU General Public License version 3）](LICENSE)是一个自由、开源的软件许可证，它保证了用户运行、学习、分享和修改软件的自由。
完整的[GPLv3](LICENSE)许可证文本包含在本项目的[LICENSE](LICENSE)文件中。在使用、修改或分发本项目的代码之前，请确保你已阅读并理解了[GPLv3](LICENSE)许可证的全部内容。

## 致谢

- [Espressif Systems](https://www.espressif.com/) 的 ESP32-C3
- [Arduino 框架](https://www.arduino.cc/) 社区
- [Bluetooth SIG](https://www.bluetooth.com/) 的 BLE 标准
- [Microsoft Learn](https://learn.microsoft.com/en-us/windows/win32/secauthn/credential-providers-in-windows) 的 Windows 凭证提供程序文档

---

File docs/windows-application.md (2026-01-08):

# SparkinWin Windows Application Guide

## Overview

SparkinWin is the Windows supporting software for the MYNOVA-Sparkin wireless Bluetooth fingerprint recognition device. It provides the necessary components to integrate the device with Windows systems, enabling fingerprint-based authentication and system login.

## System Architecture

The Windows application suite consists of four main components:

```
┌─────────────────────────────────────────────────────────────────┐
│                       SparkinWin Suite                          │
└─────────────┬───────────────────┬───────────────────────────────┘
              │                   │
┌─────────────▼─────────┐ ┌───────▼─────────────┐ ┌────────────────────┐
│ Sparkin Service       │ │ Sparkin Client      │ │ Sparkin Credential │
│ (Background Service)  │ │ (Configuration App) │ │ Provider           │
└─────────────┬─────────┘ └─────────────────────┘ └──────────┬─────────┘
              │                                              │
              │          ┌─────────────────────┐             │
              │          │ Sparkin Lib         │             │
              │          │ (Shared Library)    │             │
              │          └─────────┬───────────┘             │
              │                    │                         │
┌─────────────▼──────────┐ ┌───────▼─────────────┐ ┌─────────▼──────────┐
│ Bluetooth Communication│ │ Cross-component     │ │ Windows Credential │
│ (BLE Protocol)         │ │ Communication       │ │ Manager Integration│
└────────────────────────┘ └─────────────────────┘ └────────────────────┘
```

## Core Components

### 1. Sparkin Service

**Type**: Windows Background Service

A Windows service that runs in the background to manage communication between the Sparkin device and Windows system:

- **Bluetooth Management**: Handles BLE connections with the Sparkin device
- **Message Processing**: Interprets messages from the device
- **System Integration**: Communicates with Windows Credential Manager
- **Automatic Startup**: Launches automatically when Windows starts
- **Error Handling**: Logs errors and provides diagnostics

### 2. Sparkin Client

**Type**: Windows Desktop Application

A user-friendly configuration client for managing the Sparkin device:

- **Device Pairing**: Connects and pairs with Sparkin devices
- **Fingerprint Management**: Enrolls, deletes, and manages fingerprints
- **System Login Setup**: Configures Windows login integration
- **Device Settings**: Adjusts sleep timeout, Bluetooth settings, etc.
- **Device Information**: Displays battery level, firmware version, etc.

### 3. Sparkin Credential Provider

**Type**: Windows Credential Provider DLL

Integrates with Windows Credential Manager to enable fingerprint login:

- **Login Screen Integration**: Adds fingerprint authentication option to Windows login screen
- **Secure Authentication**: Validates fingerprint matches
- **Password Management**: Securely stores and uses Windows login credentials
- **Multi-user Support**: Works with multiple Windows user accounts

### 4. Sparkin Lib

**Type**: Shared Library (C#)

A common library shared by all SparkinWin components:

- **Bluetooth Communication**: Provides BLE protocol implementation
- **Inter-process Communication**: Facilitates communication between components
- **Configuration Management**: Handles application settings
- **Logging**: Provides unified logging functionality
- **Data Structures**: Defines common data types and message formats

## File Structure

```
SparkinWin/
├── SparkinClient/               # Configuration Application (C# WPF)
│   ├── Images/                  # Application images and icons
│   ├── Languages/               # Localization resources
│   ├── Properties/              # Project properties
│   ├── Updater/                 # Application update functionality
│   ├── ViewModel/               # MVVM view models
│   ├── AboutWindow.xaml/.cs     # About dialog
│   ├── App.xaml/.cs             # Application entry point
│   ├── MainWindow.xaml/.cs      # Main configuration window
│   ├── RegisterWindow.xaml/.cs  # Fingerprint registration window
│   ├── RenameWindow.xaml/.cs    # Fingerprint rename window
│   ├── UpdateWindow.xaml/.cs    # Update dialog
│   ├── SparkinClient.csproj     # Project file
│   └── app.manifest             # Application manifest
├── SparkinCredentialProvider/   # Windows Credential Provider (C++)
│   ├── SparkinCredentialProvider.vcxproj
│   ├── CSampleProvider.cpp/h    # Main provider implementation
│   ├── CSampleCredential.cpp/h  # Credential implementation
│   ├── CPipeListener.cpp/h      # Inter-process communication
│   ├── helpers.cpp/h            # Utility functions
│   ├── common.h                 # Common definitions
│   ├── Dll.cpp/h                # DLL entry points
│   ├── guid.cpp/h               # GUID definitions
│   ├── resource.h               # Resource definitions
│   ├── resources.rc             # Resource file
│   ├── Register.reg             # Registration script
│   └── Unregister.reg           # Unregistration script
├── SparkinLib/                  # Shared Library (C#)
│   ├── Bluetooth/               # Bluetooth communication
│   ├── PipeLine/                # Inter-process communication
│   ├── Properties/              # Project properties
│   ├── Structs/                 # Data structures
│   ├── Tools/                   # Utility tools
│   ├── ConfigManager.cs         # Configuration management
│   ├── LogUtil.cs               # Logging utilities
│   ├── SparkinLib.csproj        # Project file
│   └── XMLHelper.cs             # XML processing
├── SparkinService/              # Windows Service (C#)
│   ├── Properties/              # Project properties
│   ├── MainService.cs           # Service implementation
│   ├── Program.cs               # Service entry point
│   ├── SparkinService.csproj    # Project file
│   ├── SparkinServiceInstaller.cs  # Service installer
│   ├── InstallService.bat       # Installation script
│   └── UninstallService.bat     # Uninstallation script
└── Sparkin.sln                  # Solution file
```

## Development Environment

### Prerequisites

- **IDE**: Visual Studio 2022
- **SDK**: Windows 10/11 SDK (latest version)
- **Libraries**: 
  - Windows Bluetooth API
  - Windows Credential Provider Framework
  - C++ Standard Library

### Build Instructions

1. Open `Sparkin.sln` in Visual Studio 2022
2. Select the appropriate build configuration (Debug/Release)
3. Build the solution
4. Sign the resulting binaries (optional, but recommended for Windows 10/11)

## Installation

### Using the Installer

1. Download the latest installer from the [Releases](https://github.com/yourusername/MYNOVA-Sparkin/releases) page
2. Run the installer with administrator privileges
3. Follow the on-screen instructions
4. After installation, the Sparkin service will start automatically

### Manual Installation

1. Build the solution in Visual Studio
2. Copy the compiled files to the target directory
3. Register the credential provider DLL
4. Install and start the Sparkin service

## Configuration

### Initial Setup

1. Launch the Sparkin Client application
2. Ensure Bluetooth is enabled on your Windows system
3. Put the Sparkin device in pairing mode (press and hold the button for 3 seconds)
4. Click "Add Device" in the client app
5. Select "Sparkin FP01" from the list of available devices
6. Follow the pairing instructions

### Fingerprint Enrollment

1. Ensure the device is connected
2. Go to the "Fingerprint Management" tab
3. Click "Enroll New Fingerprint"
4. Follow the on-screen instructions to scan your fingerprint multiple times
5. Assign a name to the fingerprint for easy identification

### System Login Integration

1. Go to the "Login Settings" tab
2. Enable "Automatic Login with Fingerprint"
3. Enter your Windows login password when prompted
4. Click "Save" to complete the setup

## Communication Protocol

### Bluetooth BLE Profile

The Sparkin device uses Bluetooth BLE 5.0 for communication with Windows:

- **Service UUID**: `0000180f-0000-1000-8000-00805f9b34fb`
- **Characteristic UUIDs**:
  - `00002a19-0000-1000-8000-00805f9b34fb` (Battery Level)
  - Custom UUIDs for fingerprint data and commands

### Message Types

The system uses a binary protocol for communication:

| Message ID | Description | Direction |
|---|---|---|
| 0x01 | Fingerprint Search Result | Device → PC |
| 0x02 | Enroll Fingerprint Request | PC → Device |
| 0x03 | Enroll Fingerprint Result | Device → PC |
| 0x04 | Delete Fingerprint Request | PC → Device |
| 0x05 | Device Status Request | PC → Device |
| 0x06 | Device Status Response | Device → PC |
| 0x07 | Configuration Update | PC → Device |

## System Login Integration

### Windows Credential Provider Flow

```
1. User sees Windows login screen
2. User selects "Fingerprint" authentication option
3. Credential provider sends request to Sparkin Service
4. Service sends request to Sparkin device
5. Device waits for fingerprint scan
6. User scans fingerprint
7. Device processes and matches fingerprint
8. Device sends result to Service
9. Service sends result to Credential Provider
10. If successful, Credential Provider authenticates user
11. Windows logs in the user
```

### Security Considerations

- Windows login credentials are stored securely using Windows Credential Manager
- Fingerprint data never leaves the Sparkin device (processed locally)
- Bluetooth communication is encrypted using BLE security protocols
- All components are signed with a trusted certificate to prevent tampering

## Troubleshooting

### Common Issues

1. **Device Not Found**
   - Ensure Bluetooth is enabled on your Windows system
   - Ensure the Sparkin device is in pairing mode
   - Restart the Sparkin service

2. **Fingerprint Not Recognized**
   - Try scanning your fingerprint again with a different angle
   - Re-enroll your fingerprint
   - Check if the device battery is low

3. **Login Option Not Showing**
   - Ensure the Sparkin Credential Provider is installed correctly
   - Restart your computer
   - Check if the Sparkin service is running

4. **Service Won't Start**
   - Check the Windows Event Viewer for error messages
   - Ensure you have the latest Windows updates installed
   - Reinstall the Sparkin software

### Log Files

- **Sparkin Service Logs**: `%ProgramData%\MYNOVA\Sparkin\logs\service.log`
- **Windows Event Log**: Application and Services Logs > Sparkin

## Development

### Extending the Application

#### Adding New Features

1. **Service**: Add new functionality to the Sparkin Service by extending the `SparkinService` class
2. **Client App**: Add new UI elements and functionality to the Sparkin Client application
3. **Credential Provider**: Extend the credential provider to support additional authentication scenarios
4. **Shared Library**: Add new functionality to the Sparkin Lib for shared use across components

#### Modifying the Communication Protocol

1. Update the message definitions in both the Windows service and device firmware
2. Ensure backward compatibility if modifying existing messages
3. Test thoroughly with both new and old firmware versions

## Version History

| Version | Date | Changes |
|---|---|---|
| 1.0.0 | 2023-12-15 | Initial release |
| 1.0.1 | 2023-12-20 | Improved Bluetooth connection stability |
| 1.1.0 | 2024-01-05 | Added support for multiple user accounts |

---

[Back to README](../README.md)

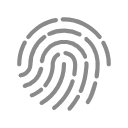
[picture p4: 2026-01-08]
SparkinWin/SparkinClient/Images/finger.png

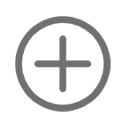
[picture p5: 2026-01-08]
SparkinWin/SparkinClient/Images/plus-circle.png

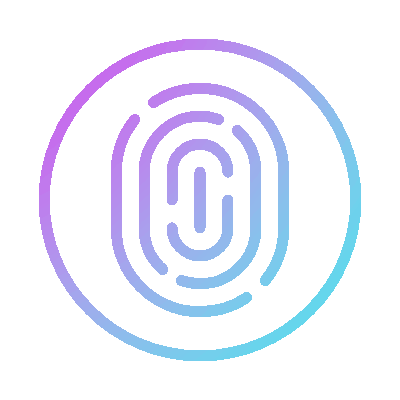
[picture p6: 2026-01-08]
SparkinWin/SparkinClient/Images/scanfinger.gif

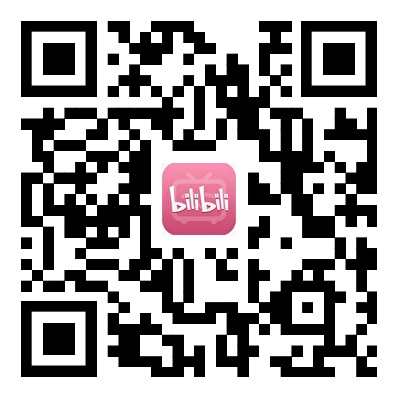
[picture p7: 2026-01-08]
SparkinWin/SparkinClient/Images/barcode_bilibili.png

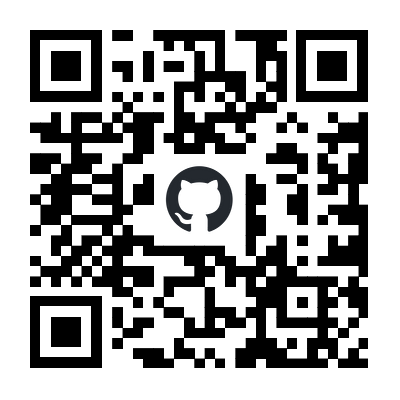
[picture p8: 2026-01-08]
SparkinWin/SparkinClient/Images/barcode_github.png

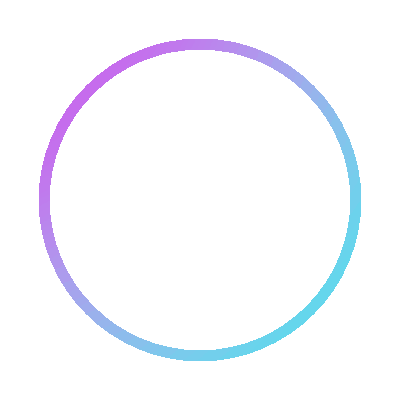
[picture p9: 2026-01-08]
SparkinWin/SparkinClient/Images/scanfinger_failed.gif

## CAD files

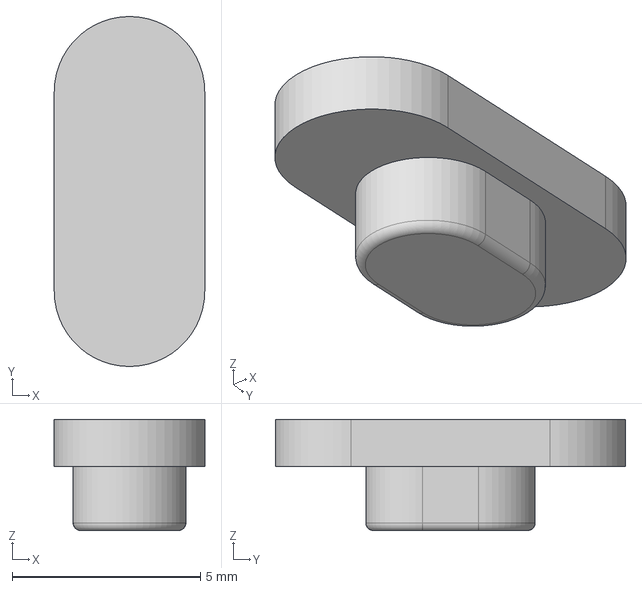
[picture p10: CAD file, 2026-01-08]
3DModels/FDM/Pairing-Button.step
4.00 x 9.30 x 2.95 mm

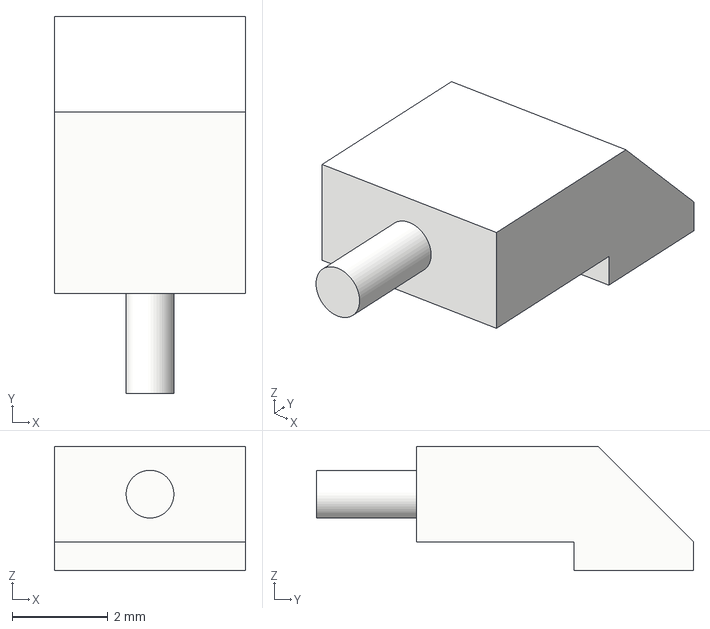
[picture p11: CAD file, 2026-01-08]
3DModels/SLA/Light-Pipe(Transparent).step
4.00 x 7.90 x 2.60 mm

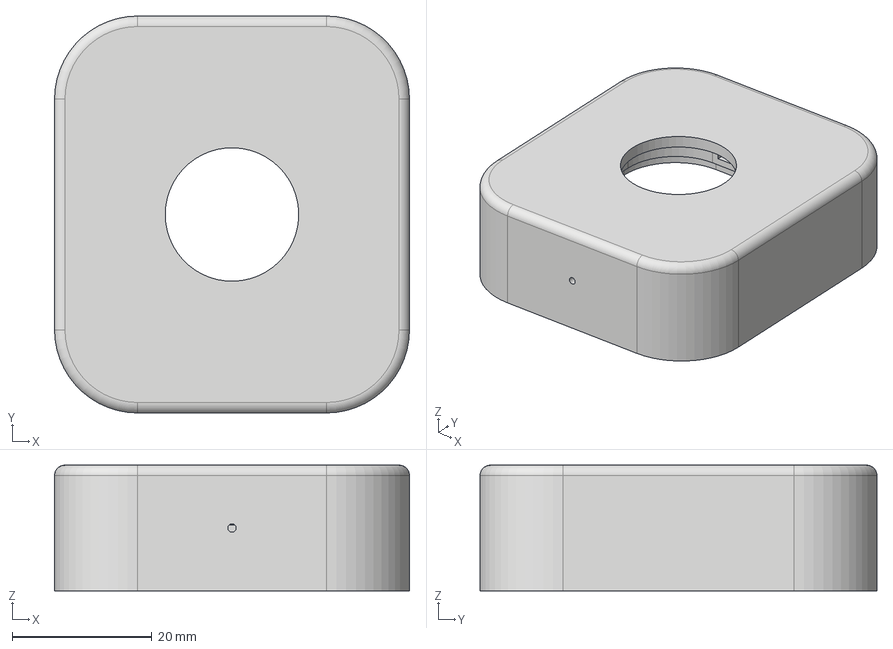
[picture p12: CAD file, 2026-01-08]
3DModels/FDM/Enclosure.step
50.8 x 56.8 x 18.0 mm

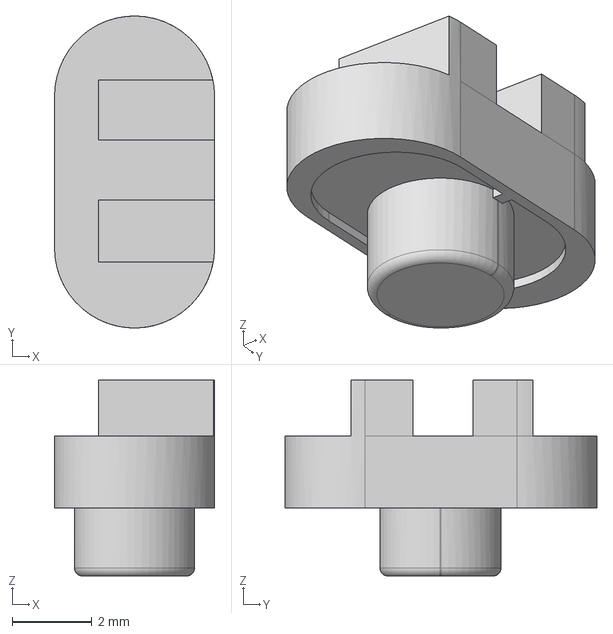
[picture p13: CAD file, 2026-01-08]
3DModels/SLA/Slide-Switch.step
4.00 x 7.80 x 4.90 mm

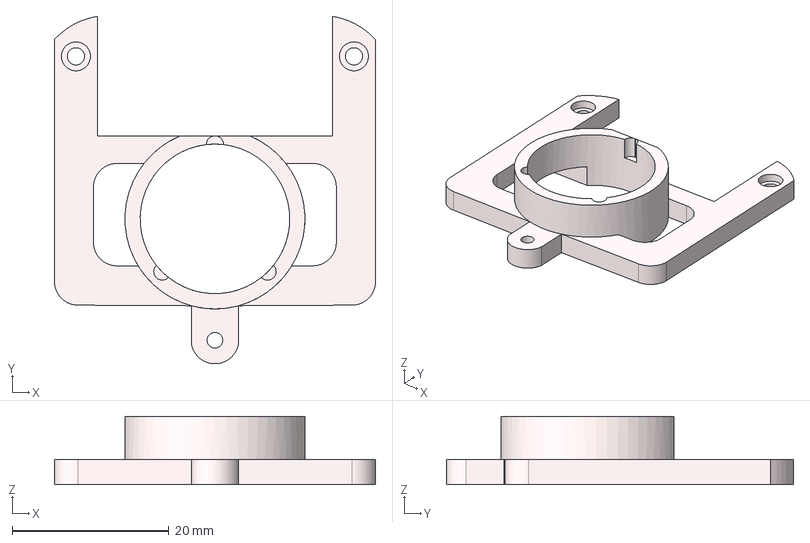
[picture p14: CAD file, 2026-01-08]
3DModels/FDM/Holder.step
41.0 x 44.4 x 8.70 mm

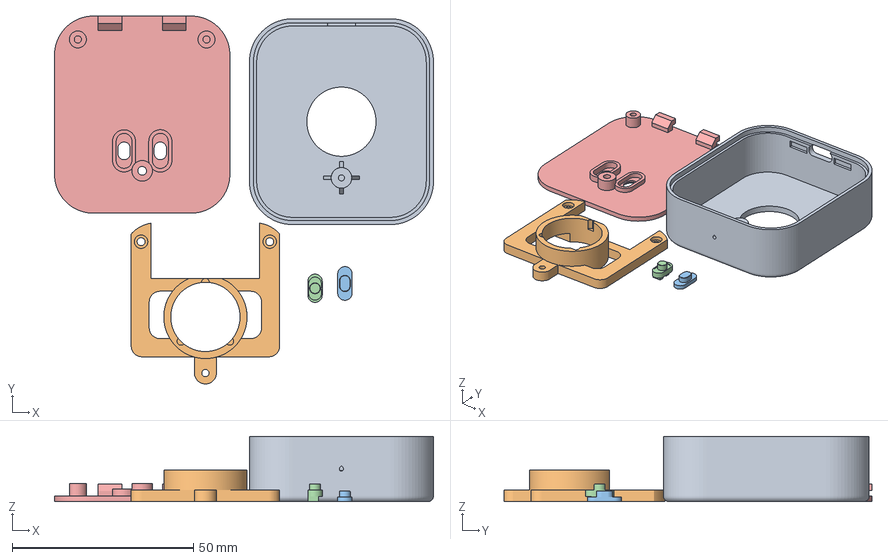
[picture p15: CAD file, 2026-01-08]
3DModels/FDM/SparkinFP_FDM.3mf
104.6 x 101.5 x 18.0 mm
外壳（FDM）.stl
SparkinFP外壳 v18-SOLID-3
配对按钮.stl
滑动开关.stl
底盖.stl

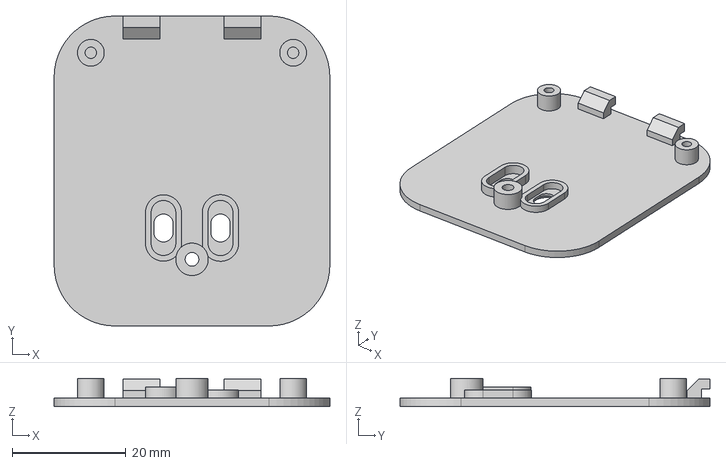
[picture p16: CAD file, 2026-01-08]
3DModels/FDM/Bottom-Cover.step
48.4 x 54.4 x 5.00 mm

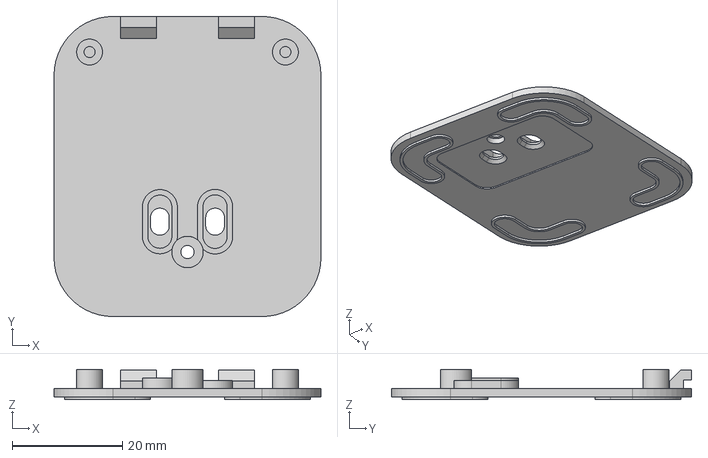
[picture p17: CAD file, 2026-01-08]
3DModels/SLA/Bottom-Cover.step
48.4 x 54.4 x 5.50 mm

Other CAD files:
3DModels/SLA/Enclosure.step

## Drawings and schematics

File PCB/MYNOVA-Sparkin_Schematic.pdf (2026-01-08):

# 单片机

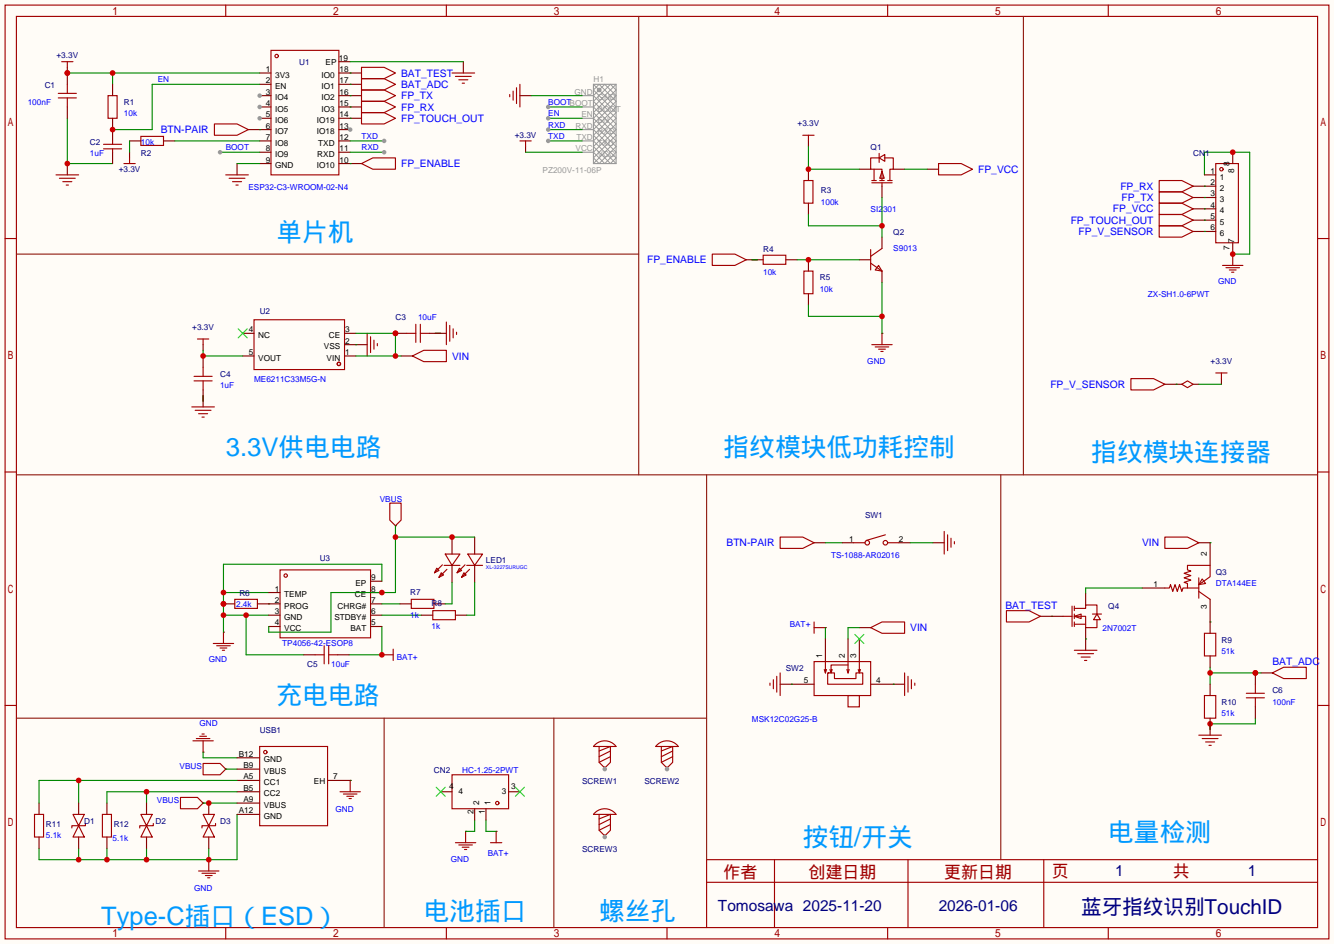
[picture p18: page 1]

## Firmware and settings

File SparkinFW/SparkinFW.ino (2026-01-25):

/*
 * Copyright (c) 2026 Tomosawa
 * https://github.com/Tomosawa/
 * All rights reserved
 */
#include <Arduino.h>
#include "esp_sleep.h"
#include "driver/rtc_io.h"

#include "IOPin.h"
#include "Fingerprint.h"
#include "BluetoothManager.h"
#include "BleKeyboard.h"
#include "BluetoothHandle.h"
#include "Common.h"
#include "ConfigManager.h"
#include "Sleep.h"
#include "Version.h"
#include "ButtonHandle.h"
#include "BatteryManager.h"
#include "SleepManager.h"
#include "UnlockManager.h"
#include "FingerprintManager.h"

#define BLUETOOTH_NAME "Sparkin FP01"

// 定义类对象
Fingerprint fingerprint(PIN_FINGERPRINT_RX, PIN_FINGERPRINT_TX);  //指纹传感器对象
BluetoothManager bluetoothManager;                                //蓝牙管理器
BleKeyboard bleKeyboard;                                          //键盘对象
ConfigManager configManager;                                      //配置信息
VersionInfo versionInfo;                                          //版本信息
ButtonHandler buttonHandler(PIN_PAIR_BUTTON);                     //按键消息处理
BatteryManager batteryManager(PIN_BATTERY_ADC, PIN_BATTERY_TEST); //电池管理器
SleepManager sleepManager;                                        //休眠管理器
UnlockManager unlockManager;                                      //解锁管理器
FingerprintManager fingerprintManager;                            //指纹消息管理器

// 用于跟踪触摸引脚的上一个状态
int lastTouchState = LOW;

void setup() {
  // 初始化串口
  Serial.begin(115200);
  Serial.println(">>>>>>>>>>Sparkin Fingerprint Started!<<<<<<<<<<");

  // 版本信息
  versionInfo.deviceId = String(ESP.getEfuseMac(), HEX);
  versionInfo.buildDate = String(__DATE__);
  versionInfo.firmwareVersion = String(FIRMWARE_VERSION);
  String device_info = "FIRMWARE:\tV" + versionInfo.firmwareVersion + " \r\nBUILD DATE:\t" + versionInfo.buildDate + " \r\nDEVICE ID:\t" + versionInfo.deviceId;
  Serial.println(device_info);

  // 初始化配置管理器
  configManager.begin();
  configManager.load();
  
  // 初始化指纹模组
  fingerprint.begin(57600);
  fingerprint.setPower(true);  // 开启指纹模组电源
  fingerprint.waitStartSignal();  // 等待指纹模组启动信号
  // 上电打印模组基本参数
  fingerprint.readInfo();
  // 设置初始等待颜色
  fingerprint.setLEDCmd(Fingerprint::LED_CODE_BLINK,0x06,0x11,0x00,4);  // 黄色闪烁灯

  // 检查电池电量初始化
  batteryManager.init();

  // 初始化蓝牙
  bluetoothManager.begin(BLUETOOTH_NAME, &bleKeyboard);
  bluetoothManager.setMessageCallback(handleBluetoothMessage);
  bluetoothManager.setAutoReconnect(true);  // 启用自动重连

  // 按键事件
  buttonHandler.begin();

  // 初始化事件组
  init_event_group();

  // 引脚初始化
  pinMode(PIN_PAIR_BUTTON, INPUT_PULLUP);
  pinMode(PIN_FINGERPRINT_TOUCH, INPUT_PULLDOWN);
  attachInterrupt(digitalPinToInterrupt(PIN_FINGERPRINT_TOUCH), handleTouchInterrupt, RISING);

  // 初始化休眠管理器
  sleepManager.begin();
  // 初始化解锁管理器
  unlockManager.begin(&sleepManager);
  // 初始化指纹消息管理器 
  fingerprintManager.begin(&sleepManager, &unlockManager);

  // 立即检查电池电量
  batteryManager.CheckBatteryLow();

  Serial.println("==========Init Completed!==========");
}

void loop() {
  // 更新蓝牙状态
  bluetoothManager.loop();
  
  // 休眠管理
  sleepManager.loop();

  delay(50);
}

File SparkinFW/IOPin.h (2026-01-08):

/*
 * Copyright (c) 2026 Tomosawa
 * https://github.com/Tomosawa/
 * All rights reserved
 */
#ifndef IOPIN_H
#define IOPIN_H

// 定义指纹模组的UART引脚
#define PIN_FINGERPRINT_RX      2
#define PIN_FINGERPRINT_TX      3
#define PIN_FINGERPRINT_TOUCH   19
#define PIN_FINGERPRINT_POWER   10
#define PIN_PAIR_BUTTON         7
#define PIN_BATTERY_TEST        0
#define PIN_BATTERY_ADC         1

#endif

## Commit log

2026-01-08 Initial
    Initial Commit
    [Bottom-Cover.step, Enclosure.step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]
2026-01-25 Fix reboot unpair bug
    Resolved the issue causing service connection failure and an “unpaired” notification following a system reboot. Optimized the connection detection mechanism for paired devices.
    [BatteryManager.cpp, BluetoothHandle.cpp, BluetoothManager.cpp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]
2026-01-31 fix pair address change bug
    Fixed an issue where the Bluetooth address would still change after a successful pairing.
    [BluetoothManager.cpp]
2026-02-09 V1.5 Update
    Added support for fingerprint-based authentication in UAC (User Account Control) prompts
